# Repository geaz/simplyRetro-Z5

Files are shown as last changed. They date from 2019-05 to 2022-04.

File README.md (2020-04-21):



This repository contains everything to rebuild the *simplyRetro Z5*.
The *Z5* is my first attempt to build a custom emulation handheld from scratch.
It runs a custom linux image for emulation to accomplish a fast boot time (10 seconds).
But you are also able to use Retropie or Lakka for example (in both case you will loose the on screen battery indicator).

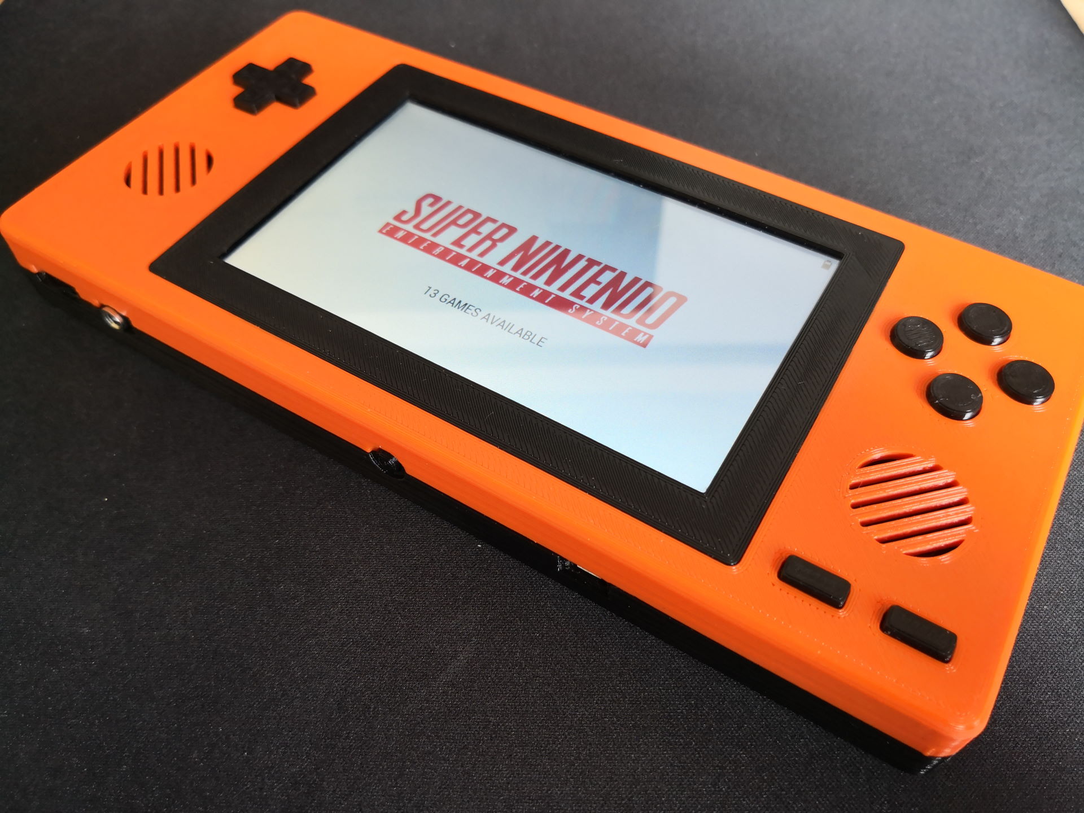
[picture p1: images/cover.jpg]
simplyRetro Z5


You can find a small video of it in action on [Youtube](https://www.youtube.com/watch?v=HvgBQ3S0Ykw).

## Warning
This is my first self designed retro handheld. So please be aware that it could contain some flaws. Furthermore you should be able to handle a soldering iron and you have to understand basic circuits, if you want to rebuild the Z5. Please make sure that you understand the steps in the build section, before you decide to rebuild the handheld.

## Features
- Custom 3D printed shell
- Custom linux distribution for fast boot ([from button press to emulationstation in 10 seconds](https://imgur.com/a/TFRGUFs))
- Single press power on and long press power off
- Battery Monitor icon and safe shutdown
- Stereo Speakers, Audio Jack and Volume Control
- 12 Buttons
- 5 inch display
- Raspberry Pi Zero powered

The Pi Zero and the 5 inch display are the reason for the naming *Z5*.

## 3D Model
The model was designed in Fusion360. If you want to change the design, you can find the whole model [here](https://a360.co/2GZACGc). The STLs are in the Thingiverse downloads and the Github repository. Furthermore there are exported STEP and Fusion360 Archive Files ready to download.

## BOM

- 3D Printed Shell (STL folder for models)
- [Elecrow 5 inch Display](https://www.elecrow.com/5-inch-hdmi-800-x-480-capacitive-touch-lcd-display-for-raspberry-pi-pc-sony-ps4.html) (If you want to use another display, make sure to adapt the shell) 
- [12x Adafruit Softbuttons](https://www.adafruit.com/product/3101)
- 1x 5mm Tactile Button for the Power Button
- [1x Powerboost 1000c](https://www.adafruit.com/product/2465)
- [2x Speaker](https://www.reichelt.de/kleinlautsprecher-k-34-wp-1w-8ohm-vis-2981-p204642.html?&trstct=pos_0) (or similar, just make sure they are 1W, 8Ohm and have a diameter of 3.4 cm)
- [FPV HDMI Adapter](https://de.aliexpress.com/item/FPV-Micro-HDMI-Mini-HDMI-90-grad-Adapter-5-cm-100-cm-FPC-Band-Flache-Hdmi/32833580742.html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) (1xA1, 1xC1 and 1x5cm Cable)
- 1x MCP3008 ADC
- 1x Volume potentiometer (I took a GameBoy Color replacement part)
- [1x Jack Plug PJ-307](https://de.aliexpress.com/item/Hot-10-Pcs-5-Pin-3-5mm-Weibliche-Audio-Stereo-Jack-Buchse-PJ-307-PJ307-3F07/32955627960.html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)
- 1x PAM8403 (Audio AMP)
- 1x 2500 mAh LiPo ([like this one](https://www.ebay.de/itm/LiPo-Akku-Lithium-Ion-Polymer-Batterie-3-7V-2500mAh-JST-PH-Connector-ZB07008/283213408497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))
- [Stripboard](https://www.amazon.com/ST3U-StripBoard-3U-Uncut-Strips-Sided/dp/B00C9NXP94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) (if you want to use the same circuits as me for the battery monitoring and safe shutdown)
- Some M3x8mm screws (Mounts and Shell), M2.5x4mm screws (Electronics) and one M2.5x8mm screw (Top screw on the bottom shell, has to be smaller to get it fit)
- Resistors (6,8K, 10K, 100K)
- 1N4001 Diodes
- Velcro or double-faced adhesive tape to attach the PAM and circuits
- Wire :)

### Alternative BOMs

Thanks to [AxelNobody](https://www.thingiverse.com/AxelNobody/about)! He created a [alternative BOM](https://github.com/geaz/simplyRetro-Z5/blob/master/BOM%20-%20US.md) with shop links for US citizens.

## Build
This chapter should help you to build the Z5. If you are missing something, or think it could be phrased better, you are free to create a *Pull Request* on Github. This way, together we can create a guide which is easy to understand! I will always keep the description on Thingiverse in sync to the *Readme* on Github.

**Again, please be aware, that you should have basic soldering skills and you should be able to understand basic circuits. Make sure that you understand the steps in the build section, before you decide to rebuild the handheld.**

I hope you got all your parts. Now it is time to assemble the Z5. 

### Buttons
This part is easy. Take all your printed button mounts and insert the *Adafruit SoftButtons* into them. It should be a tight fit. Use a pliers, if necessary and bend one of the four button pins to prevent it to fell out from the mount. Insert the printed DPad and buttons into the upper shell and screw the populated button mounts on top. **On the DPad please don't insert the upper right screw, and on the button mount the upper left screw, yet. These holes will be used to fasten the bottom half of the shell.** The *Shoulder Buttons* and *Shoulder Button Mounts* will be inserted into the shell before it gets closed. 

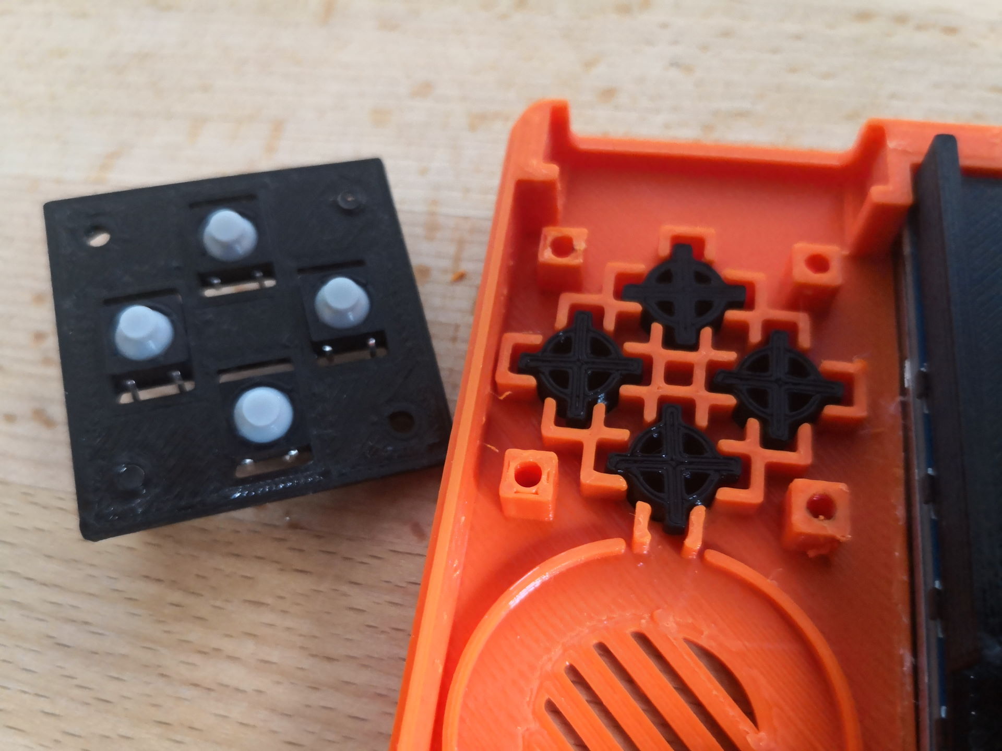
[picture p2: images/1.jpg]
simplyRetro Z5 - Buttons


### Display
**You have to install the display rotated by 180°**. Otherwise we will get space problems with the HDMI connectors. 

To fit the display into the shell, you have to cut off half of the bottom display mounts. 
Please use the following two pictures as a reference.  
**Make sure you understand how to place the display, in the correct orientation, into the shell BEFORE you cut the mounts!**

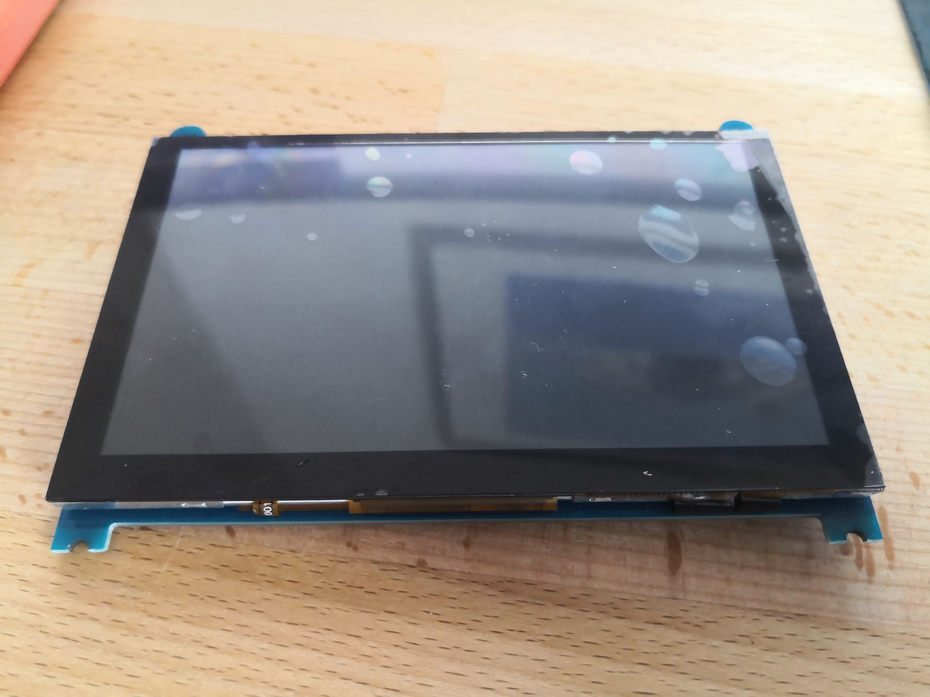
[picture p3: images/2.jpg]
simplyRetro Z5 - Display cutted


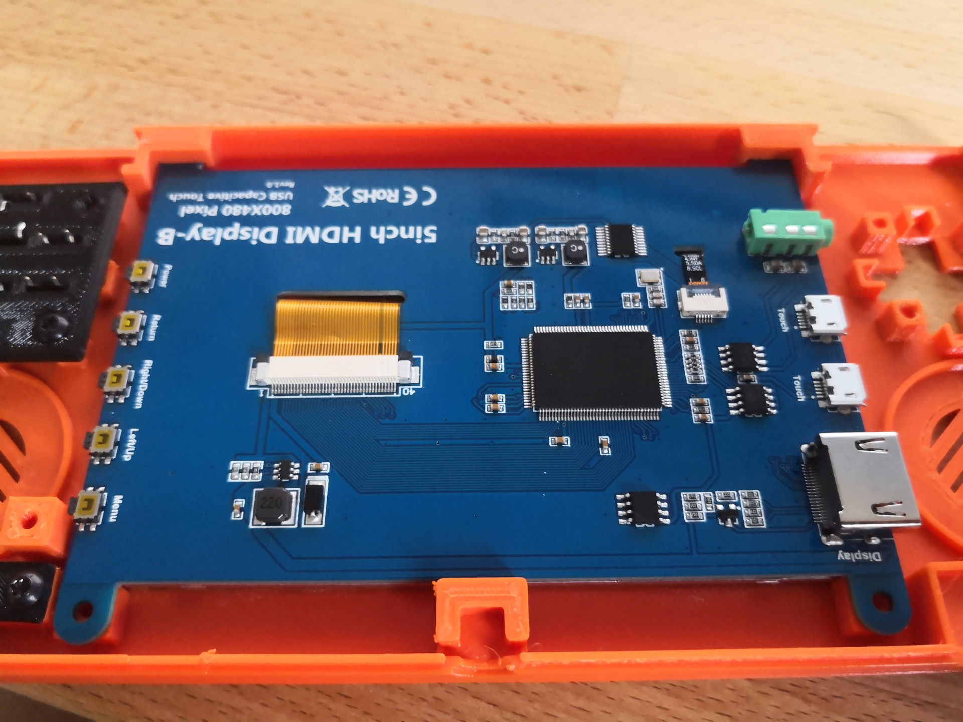
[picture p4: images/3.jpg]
simplyRetro Z5 - Display assembled


If your display is fitting into the top shell, you can remove it to glue the *Display Frame* to the upper shell. I used super glue. **Give it enough time to dry before you proceed. Otherwise you will ruin your display!**

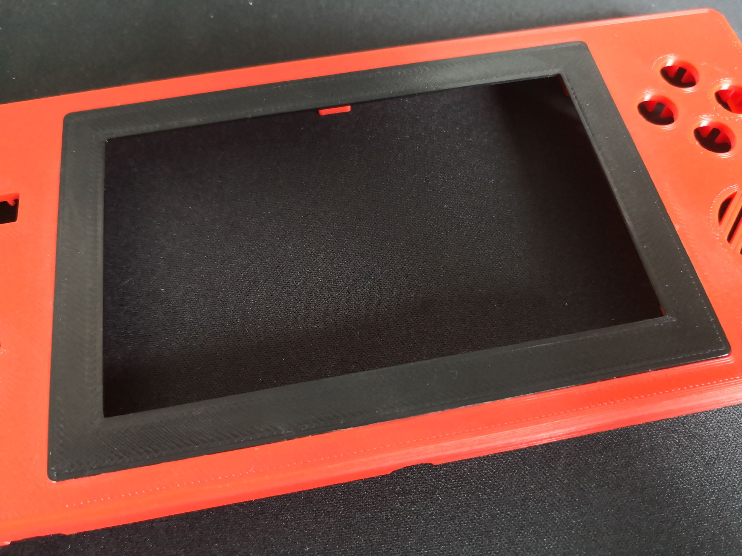
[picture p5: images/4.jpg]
simplyRetro Z5 - Display Frame


### Electronic Mount
Now take the *Electronic Mount* and use for example a bit felt at the edge without mount holes (see the following picture). The felt just acts as a spacer between the display PCB and the *Electronic Mount*.

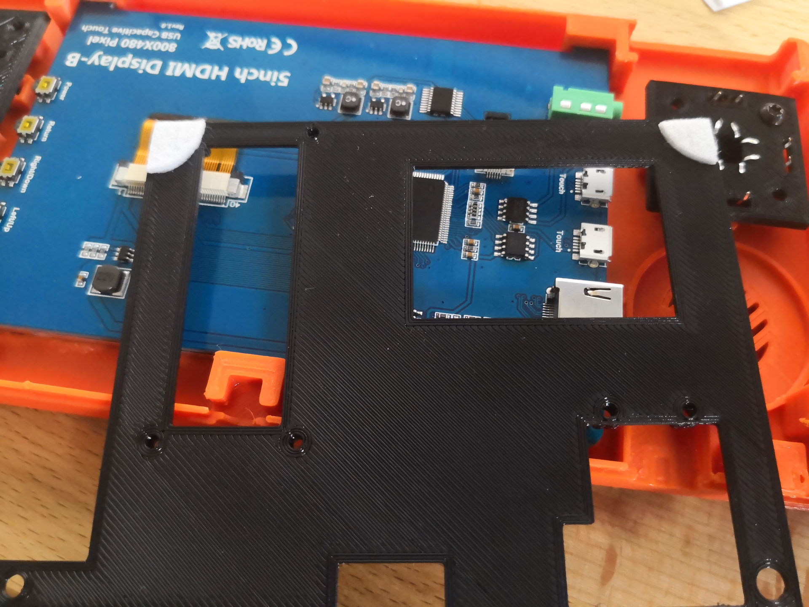
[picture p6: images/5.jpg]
simplyRetro Z5 - Electronic Mount Felt


Now take the printed spacers and two M3x8mm screws and attach the mount to the display.

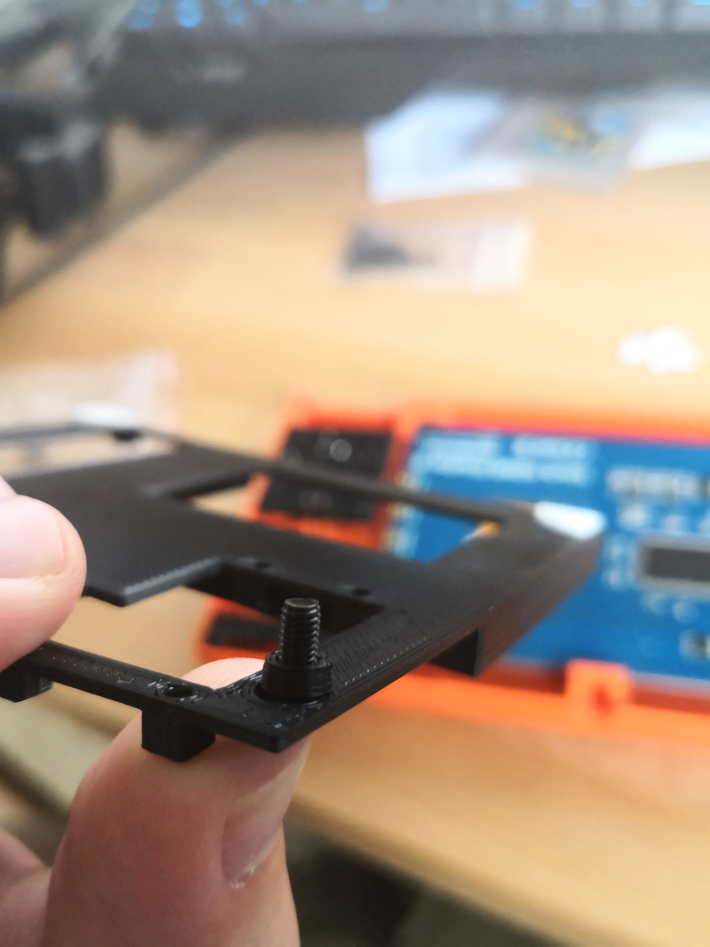
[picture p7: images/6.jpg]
simplyRetro Z5 - Electronic Mount Spacers


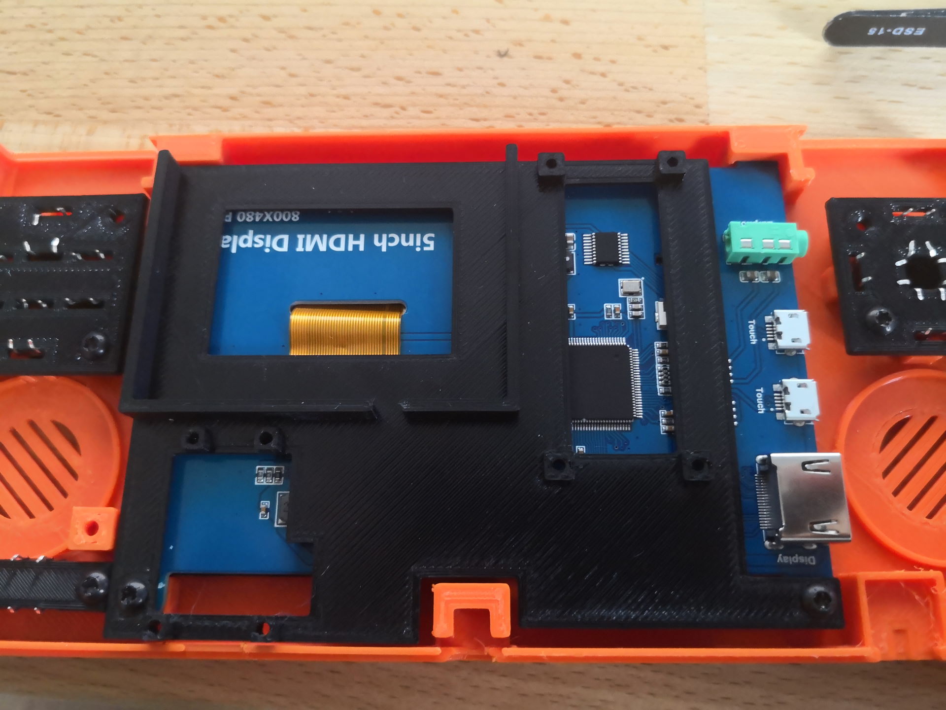
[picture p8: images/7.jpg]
simplyRetro Z5 - Electronic Mount assembled


### Power
To power the Raspberry Pi Zero through the Powerboost 1000C, I soldered the PowerBoost to the USB test pads of the Raspberry Pi. 
I used the same pads to solder a short Micro USB cable (I used the one which came with the display) to power the display. Unfortunately I don't have a picture of this.
Just search for the pinout of a micro USB adapter. You just need the *Vcc* and *GND*. If you are not sure which cable is which on your adapter, try to measure it with a multimeter.

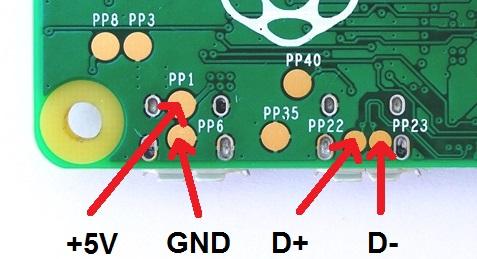
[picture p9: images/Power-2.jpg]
simplyRetro Z5 - Test Pads

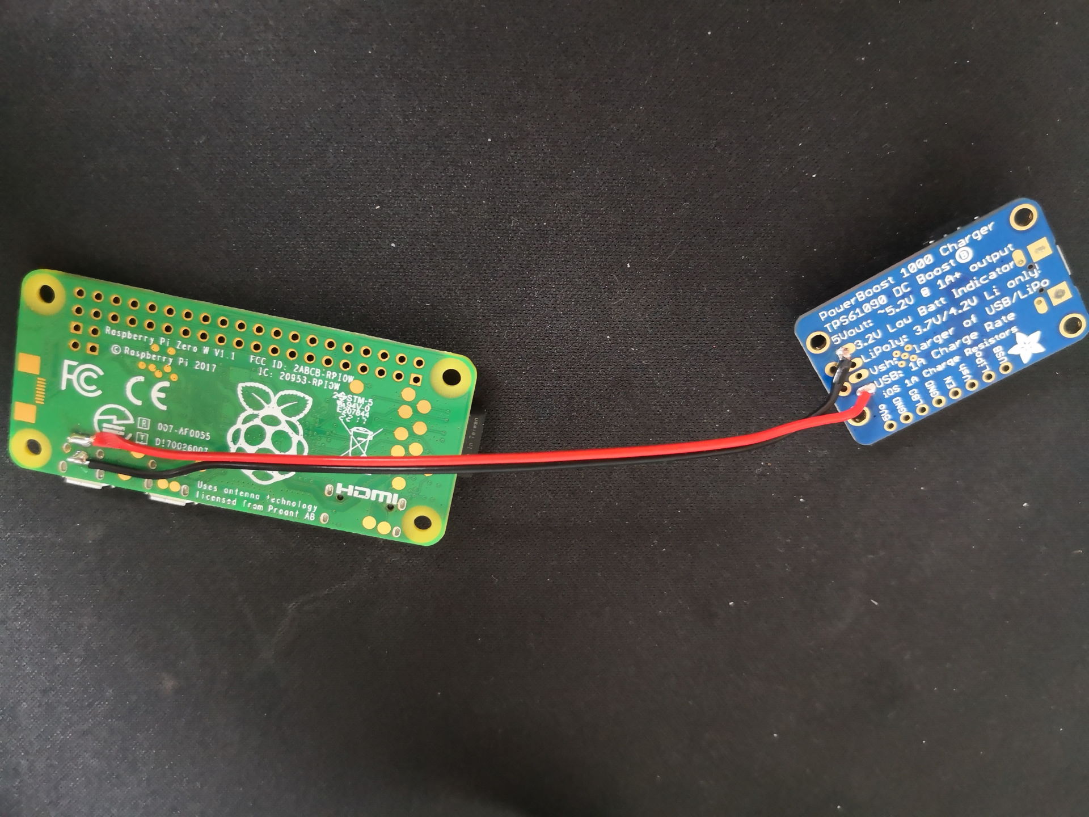
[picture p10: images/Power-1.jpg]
simplyRetro Z5 - PowerBoost Soldered


Now you need to do your first little circuit for this project. The circuit to power the Pi on and off.
You will need a piece of the Stripboard, the single tactile switch, three diodes, 1x100k and 2x10k resistors. 
Before you start soldering, you should do the needed cuts on the Stripboard. 

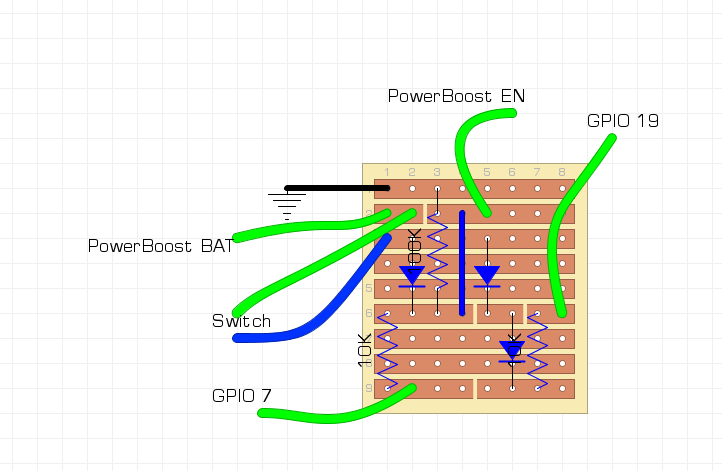
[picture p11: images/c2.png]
simplyRetro Z5 - Power Circuit


The circuit needs a bit of explanation. If the switch is not pressed, the *Enable* pin of the *PowerBoost* gets pulled to ground. This way the *PowerBoost* will be disabled when a battery is connected. As soon as the switch gets pressed, the *Battery* pin of the *PowerBoost* gets connected to the *Enabled* pin. This will enable the *PowerBoost*. Because we connected GPIO 7 of the Pi to the board the *Enable* pin will stay *HIGH* when the switch gets released and the board will stay powered on. You are able to use another pin than GPIO 7, but you have to make sure that you use a pin which is *HIGH* per default. 

GPIO 19 is used as the power off pin. The *simplyRetro Z5* custom distribution contains a small tool which listens to GPIO 19. If this pin gets *HIGH* and stays *HIGH* for a small amount of time a shutdown of the Pi gets initiated. 

Because of the line

*dtoverlay=gpio-poweroff,gpiopin=7,active_low=1*

in the config.txt, GPIO 7 will go *LOW*, if the Pi is shutdown. This disables the *PowerBoost* again.

Attach the switch into the bottom of the top shell half. I took a little drop of super glue to fix it in place.

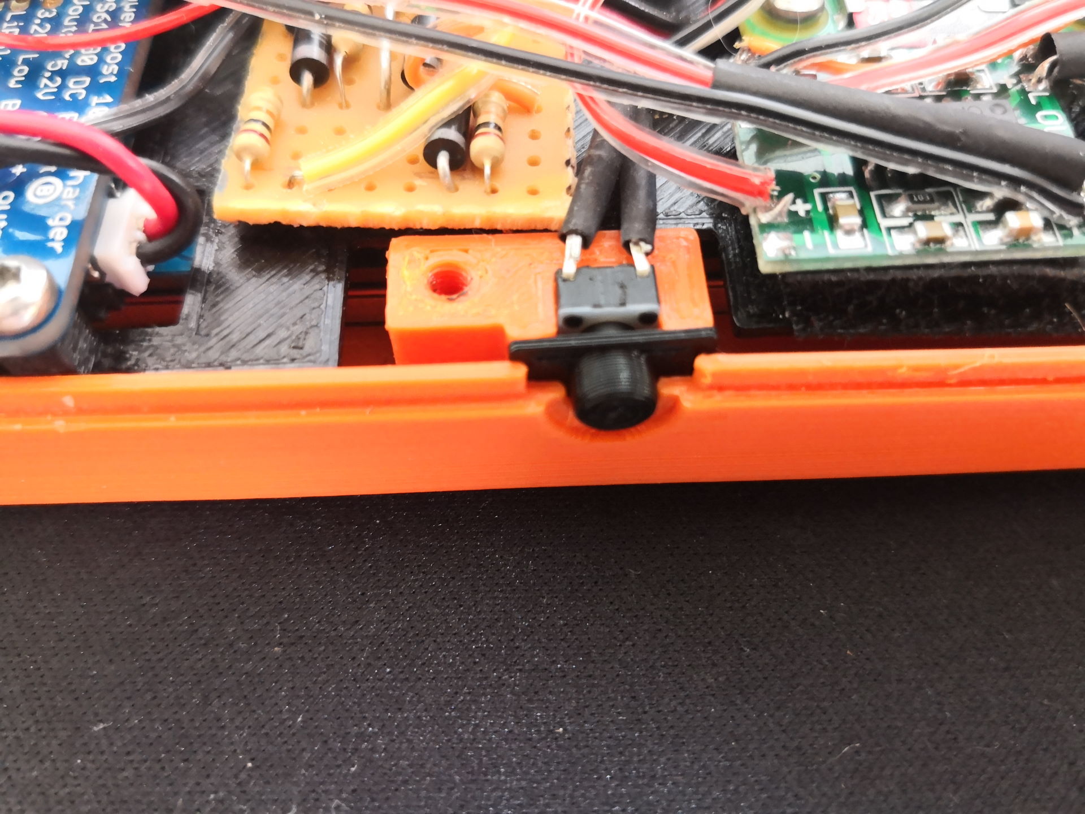
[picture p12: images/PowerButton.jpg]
simplyRetro Z5 - Power Button


Because the battery monitor and the controller also need several ground wires, I cutted an additional piece of Stripboard of 1x5 in size and used this as a single ground to the Pi.

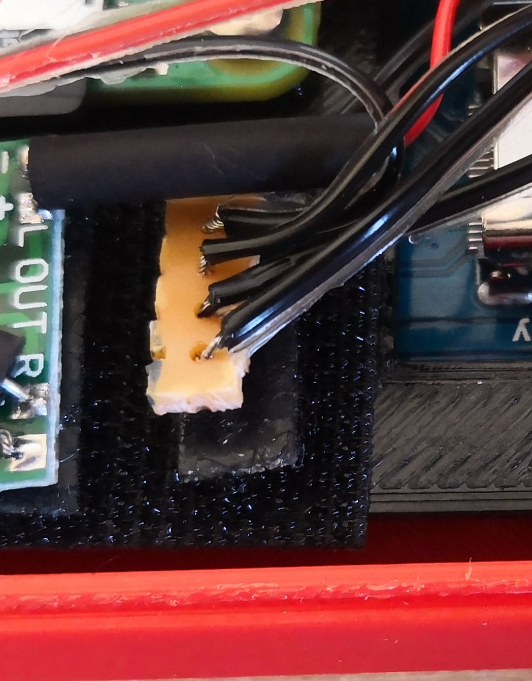
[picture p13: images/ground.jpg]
simplyRetro Z5 - Ground


### Controls
The *simplyRetro Z5* uses *Adafruits Retrogame* for its controller inputs. 

To make the softbuttons work, each button has to be connected to ground and one pin on the Raspberry Pi.
I connected the ground pins on the DPad together and used just one ground pin on the Raspberry Pi for all four buttons.
I did the same for the four buttons on the right and the *Start*, *Select* button. You could also use a piece of Stripboard to just use one
ground pin of the Raspberry Pi and connect all ground wires of the buttons just to this Stripboard.

If you want to use the exact same configuration for *Retrogame* you can use the following pins.

```
LEFT      16  # Joypad left
RIGHT     17  # Joypad right
DOWN      4   # Joypad down
UP        2   # Joypad up
Z         23  # 'B' button 
X         24  # 'A' button 
A         0   # 'Y' button 
S         25  # 'X' button 
Q         26  # Left shoulder button
W         5   # Right shoulder button
SPACE	  22  # 'Select' button
ENTER     27  # 'Start' button
```

### Audio
The *simyplRetro Z5* takes the audio source directly from the HDMI display. Use a piece of the Stripboard (1x4 in size) as the ground connection.
**Don't connect the ground of the PAM! Otherwise you will create a ground loop which will cause interferences in you audio circuit!**

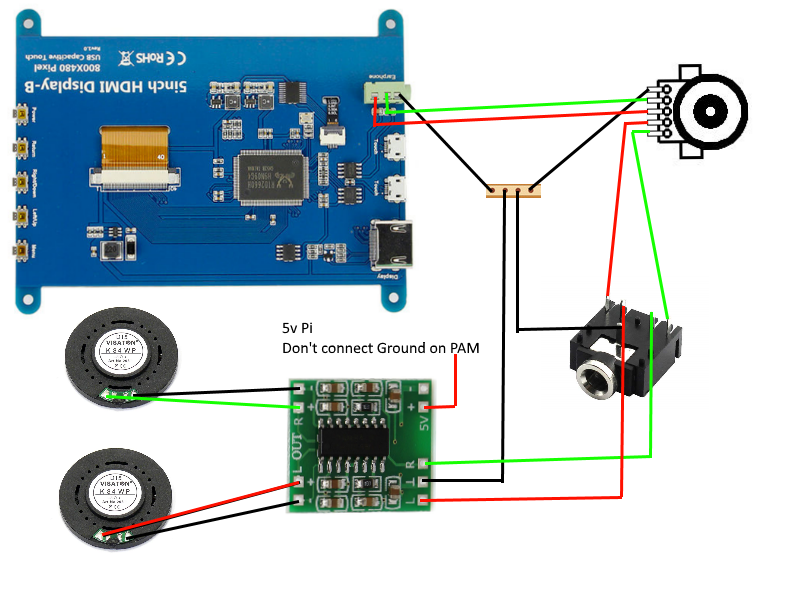
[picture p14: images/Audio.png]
simplyRetro Z5 - Audio


I attached the potentiometer with a little drop of hot glue. The audio jack plug should be press fit.

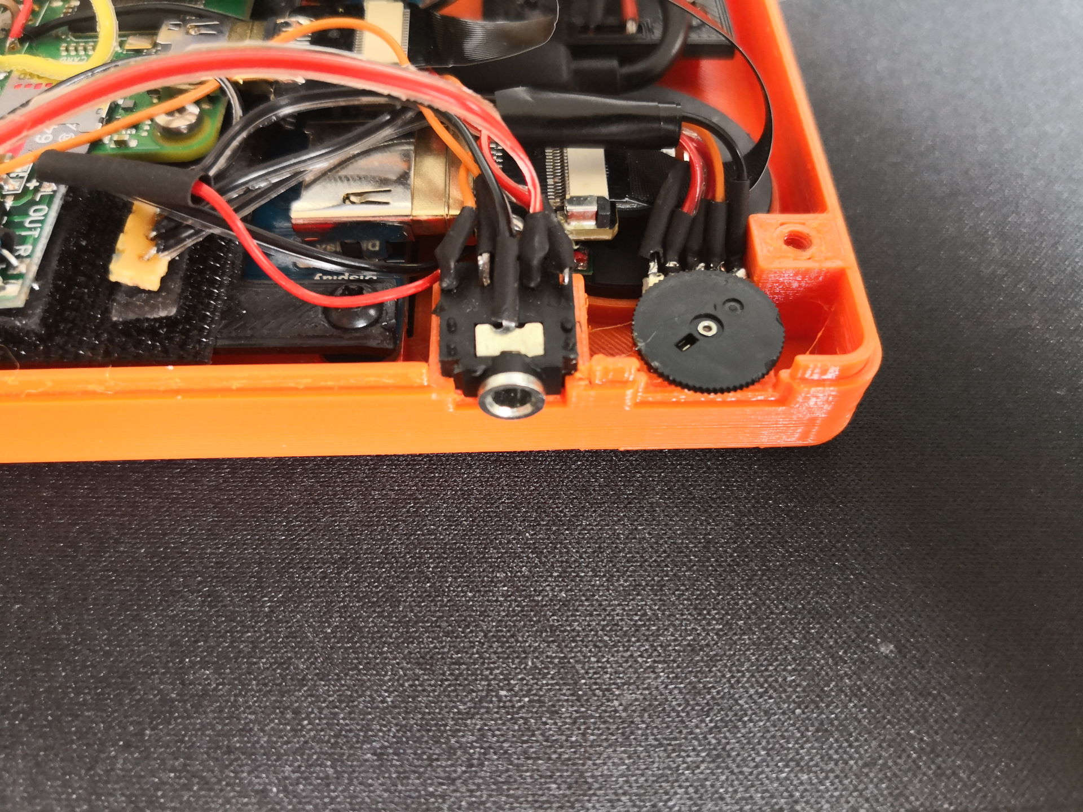
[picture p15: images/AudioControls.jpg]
simplyRetro Z5 - Audio


### Battery Monitor
For this step you will again need a bit of the Stripboard, the MCP3008, two 6.8k and two 10k resistors.
Again make sure to do the cuts on the Stripboard, before you start soldering. Solder everyhing as referenced in the following picture.
You should use the exact same pins, if you want the battery monitor tool in the custom distribution to work.

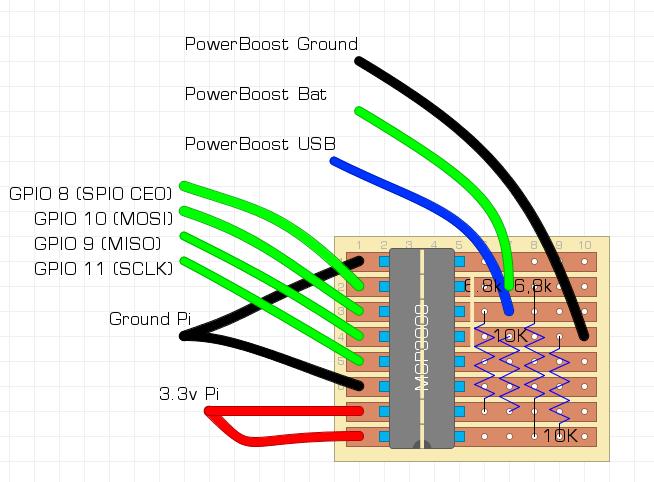
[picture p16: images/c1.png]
simplyRetro Z5 - ADC Circuit


I attached the board with Velcro on top of the right speaker.

### Closing the shell
Finally your internals may look something likes this (or not so messy...).

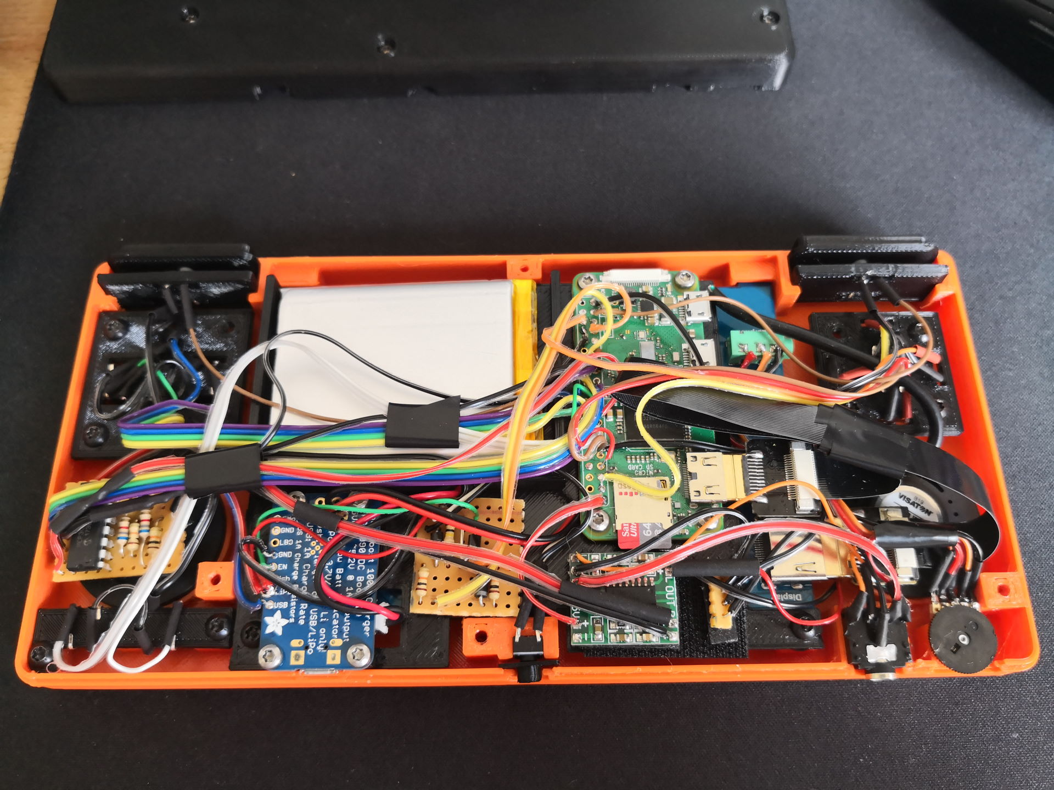
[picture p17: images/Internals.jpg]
simplyRetro Z5 - Internals


As soon as your SD card is flashed and everything is working, you are able to close the shell. Use five M3x8mm and one M2.5x8mm. Be careful, that the screw holes are free from wires. You don't want to damage them when you screw the shell halves together. After this last step is done, go and enjoy your *simplyRetro Z5*! Have fun :)

## Custom Distribution
The custom distribution can be downloaded [here](https://github.com/geaz/simplyRetro-Z5/releases).  
It is based on [BuildRoot](https://buildroot.org/) and just contains the packages needed to play on the *Z5*. 

**Please be aware, that the distribution was build for the Z5! It was not tested as a standalone distribution.**

The *Z5* uses Retroarch for all emulations. The following systems are supported at the moment (more can be added):

- Arcade (MAME2013-plus - BIOS needed)
- Gameboy DMG / Color (Gambatte)
- Gameboy Advance (gpsp - BIOS needed)
- NES (quicknes)
- SNES (snes9x2002)
- Meda Drive / Master System / Sega CD (picodrive - BIOS needed for Sega CD)

If you want to use the distribution just use Etcher to copy the img file to a SD Card.

### Boot Partition

#### config.txt
Please be aware, that the default config.txt will rotate the screen. This is necessary, if you are you using the same screen as me.

#### retrogame.cfg
The Z5 uses RetroGame by Adafruit for the controller. In this file you are able to set the pins you used during the build.

#### retropower.cfg
If you used another GPIO than pin 19 for the power off button, you are able to set it in this file. Please be aware, that you have to use the WiringPi number of the GPIO pin.
Use for example [https://de.pinout.xyz/](https://de.pinout.xyz/) to check the pin numbering. If you don't want to use the battery monitoring and/or power circuit, you are able to change the active features in this file.

### Login
Start the system and login with:

User: root  
Pass: simplyretro

### Resize Root
To use the full size of you SD Card you should execute the following two scripts in order:

/root/reformat.sh (will reboot the system after execution)  
/root/resize.sh

### WiFi, FTP & SSH
You are able to set your WiFi SSID and PSK through the Emulationstation menu. Press 'Start' and go into the 'simplyRetro' menu.
After setting the WiFi, just enable any service you need. **I recommend to disable the services after usage to reduce battery load and 
to speed up the boot process.**

### ROMs and BIOS folder
The ROMs and BIOS folder are located at */root/roms* and */root/bios*. You are able to change the splash screen, if you want. It is also located at the */root* folder.

### Controls
EmulationStation will ask you to configure your controller on the first start.  
Retro Arch is configured to exit a ROM, if you press *START + B*.  
You are able to open the Retro Arch menu while playing a game, if you press *START + A*.

### Updates
If there will be an update to the distribution, I will try to distribute the updated files together with the image. This way you are able to update just these files via FTP and don't have to flash the whole image again.

## Credits
Thanks to [NeoHorizon](https://github.com/NeonHorizon/lipopi) and [Craic](https://github.com/craic/pi_power) for the work on the power circuits. I took their work and reworked the circuit a bit and created a custom battery monitor in C.  
Thanks to [BuildRoot](https://buildroot.org/) for the creation of this great system which enabled me to create a custom linux distribution.  
Thanks to [RecalBox](https://www.recalbox.com/) for their work on the packages for BuildRoot. I took the RetroArch and LibRetro packages and reworked them a bit to work on my distribution. Also thanks for the code of the on screen keyboard!
Thanks to [ehettervik](https://retropie.org.uk/forum/topic/4611/runcommand-system-splashscreens) for the emulator splashscreens.
Thanks to [ProGM](https://progm.itch.io/doctor-how) for the GB homebrew game.

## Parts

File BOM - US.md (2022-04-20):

BOM for the US by [AxelNobody](https://www.thingiverse.com/AxelNobody/about)

| Part | Source | Notes |
|---|---|---|
| Elecrow 5 inch Display | [Amazon](https://www.amazon.com/Elecrow-Capacitive-interface-Supports-Raspberry/dp/B07FDYXPT7) |  |
| 12x Adafruit Softbuttons | [Amazon](https://www.amazon.com/gp/product/B07KKN7GPB) [Mouser](https://www.mouser.com/ProductDetail/485-3101) |  |
| 1x 5mm Tactile Button for the Power Button | [Adafruit](https://www.adafruit.com/product/367) [Mouser](https://www.mouser.com/ProductDetail/485-367) |  |
| 1x Powerboost 1000c | [Amazon](https://www.amazon.com/gp/product/B01BMRBTH2) [Mouser](https://www.mouser.com/ProductDetail/485-2465) |  |
| 2x Speaker | [Amazon](https://www.amazon.com/gp/product/B00O9YHIDA/) [Mouser](https://www.mouser.com/ProductDetail/243-K34WP-8OHM) | The Amazon speakers are suitable alternatives.  They can be attached with hot glue.  The Mouser sourced speakers are identical to the original |
| FPV HDMI Adapter (1xA1, 1xC1 and 1x5cm Cable) | [See Issue](https://github.com/geaz/simplyRetro-Z5/issues/16) |  |
| 1x MCP3008 ADC | [Adafruit](https://www.adafruit.com/product/856) [Mouser](https://www.mouser.com/ProductDetail/579-MCP3008-I-P) |  |
| 1x Volume potentiometer | [Amazon](https://www.amazon.com/gp/product/B00O9Y6Z70) [Mouser(Untested)](https://www.mouser.com/ProductDetail/688-RK10J12E0A0A) |  |
| 1x Jack Plug PJ-307 | [Adafruit](https://www.adafruit.com/product/1699) [Mouser](https://www.mouser.com/ProductDetail/485-1699) |  |
| 1x PAM8403 (Audio AMP) | [Amazon](https://www.amazon.com/gp/product/B00LODGV64/) |  |
| 1x 2500 mAh LiPo | [Adafruit](https://www.adafruit.com/product/328) |  |
| Stripboard | [Amazon](https://www.amazon.com/gp/product/B00C9NXP94) |  |
| M3x8mm screws (Mounts and Shell) | [Amazon](https://www.amazon.com/gp/product/B016YZTEDI) |  |
| M2.5x4mm screws (Electronics) | [Amazon](https://www.amazon.com/gp/product/B07HC3LQYS) |  |
| Resistor Pack (needs 6.8k, 10k, 100k) | [Amazon](https://www.amazon.com/gp/product/B016NXK6QK/) |  |
| OR |
| 6.8k Resistors | [Mouser](https://www.mouser.com/ProductDetail/660-MF1-4LCT52R682G) |  |
| 10k Resistors | [Mouser](https://www.mouser.com/ProductDetail/660-MF1-4LCT52R103G) |  |
| 100k Resistors | [Mouser](https://www.mouser.com/ProductDetail/660-MF1-4LCT52R104G) |  |
| 1N4001 Diodes | [Adafruit](https://www.adafruit.com/product/755) [Mouser](https://www.mouser.com/ProductDetail/863-1N4001G) |  |
| Velcro or double-faced adhesive tape to attach the PAM and circuits | [Amazon](https://www.amazon.com/gp/product/B00006IF60/) |  |
| Raspberry Pi Zero W | [Adafruit](https://www.adafruit.com/product/3400) [Mouser](https://www.mouser.com/ProductDetail/713-110991027) |  |
| Wire | Use what you have :) |  |

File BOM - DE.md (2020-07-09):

BOM for Germany by [Phil](https://www.thingiverse.com/leseule/)

| Part | Source | Price |
|---|---|---|
| Elecrow 5 inch Display | [Aliexpress](https://de.aliexpress.com/item/32889893278.html) | 40,49 € |
| 12x Adafruit Softbuttons | [Aliexpress](https://de.aliexpress.com/item/32668706990.html) | 2,31 € |
| 1x 5mm Tactile Button for the Power Button | [Aliexpress](https://de.aliexpress.com/item/32668706990.html) | use as the US-list a 6mm button |
| 1x Powerboost 1000c | [Digikey](https://www.digikey.de/product-detail/en/adafruit-industries-llc/2465/1528-1349-ND/5356834) | 18,12 € |
| 2x Speaker | [Aliexpress](https://de.aliexpress.com/item/33037641624.html) | 0,90 € |
| FPV HDMI Adapter (1xA1, 1xC1 and 1x5cm Cable) | [Aliexpress](https://de.aliexpress.com/item/32833580742.html) | 10,28 € |
| 1x MCP3008 ADC | [Digikey](https://www.digikey.de/product-detail/en/microchip-technology/MCP3008-I-P/MCP3008-I-P-ND/319422) | 1,94 € |
| 1x Volume potentiometer | [Aliexpress](https://de.aliexpress.com/item/32968867573.html) | 0,63 € |
| 1x Jack Plug PJ-307 | [Aliexpress](https://de.aliexpress.com/item/32955627960.html) | 0,09 € |
| 1x PAM8403 (Audio AMP) | [eBay](https://www.ebay.de/itm/5PCS-2-Channel-3W-Digital-Power-PAM8403-Class-D-Audio-Amplifier-Board-USB-DC-5V/264406885127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) | 0,46 € |
| 1x 2500 mAh LiPo | [Eckstein](https://eckstein-shop.de/LiPo-Akku-Lithium-Ion-Polymer-Batterie-37V-2500mAh-JST-PH-Connector) | 8,94 € |
| Stripboard | [Aliexpress](https://de.aliexpress.com/item/32847898011.html) | 0,92 € |
| M3x8mm screws (Mounts and Shell) | [Digikey](https://www.digikey.de/products/de/hardware-fasteners-accessories/screws-bolts/572?k=M3x8) | 0,56 € |
| M2.5x4mm screws (Electronics) | [Digikey](https://www.digikey.de/product-detail/de/essentra-components/50M025045P004/145-50M025045P004-ND/11638731) | 0,12 € |
| Resistor Pack (needs 6.8k, 10k, 100k) | [Eckstein](https://eckstein-shop.de/600x-Metallschicht-Metallfilm-Widerstaende-025W-20-bis1M-30-Sorten) | 3,53 € |
| 1N4001 Diodes | [Digikey](https://www.digikey.de/product-detail/de/comchip-technology/1N4001-G/641-1310-1-ND/1979675) | 0,09 € |
| Velcro or double-faced adhesive tape to attach the PAM and circuits | [Amazon](https://www.amazon.de/tesa-doppelseitiges-Montageband-Powerbond-Innen/dp/B0014E3L9I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) | 1 € |
| Wire Pack | [Eckstein](https://eckstein-shop.de/SparkFun-Hook-Up-Wire-Assortment-Stranded-22-AWG) | 1 € |
OR
| Wire | use what you have | |

Just ordered all parts till now (09.07.2020) due to the exactly same specs, so they should fit as planed.
Price in total at the actual day (without Raspberry Pi) around 100 €.
(Prices were calculated on the amount of usage. Also shipping costs where divided by the percentage of use.)

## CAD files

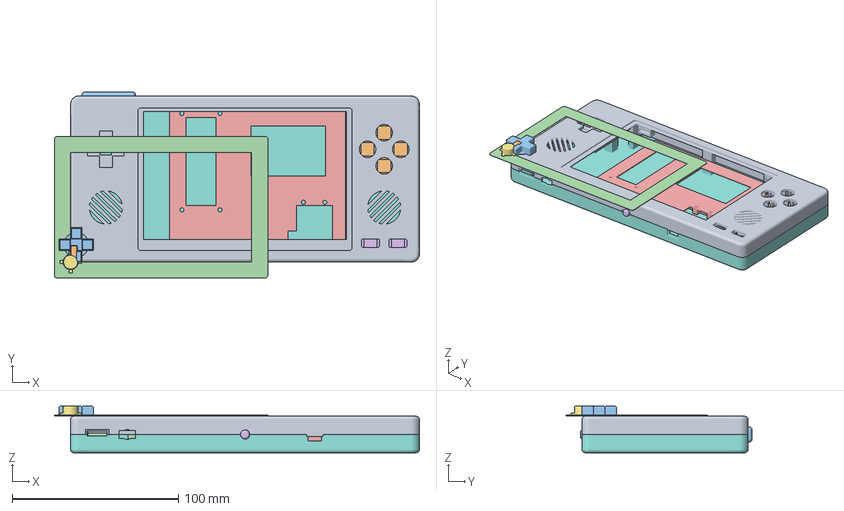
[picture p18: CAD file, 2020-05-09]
simplyRetro z5.3mf
219.7 x 112.2 x 28.0 mm
Top Shell.stl
2x Button.stl
2x Shoulder Button.stl
2x Shoulder Button Mount.stl
2x Spacer (5x3.5 - 2mm).stl
Control Mount C.stl
4x Button.stl
Bottom Shell.stl
Control Mount A.stl
Control Mount B.stl
Cross.stl
Display Frame.stl
Electronic Mount.stl
Power Button.stl

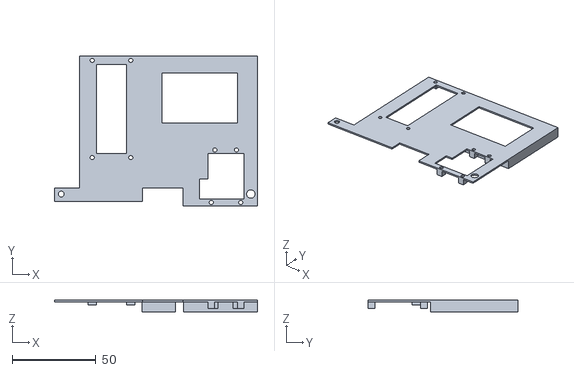
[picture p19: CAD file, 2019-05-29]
stl/Electronic Mount.stl
121.1 x 89.3 x 7.00

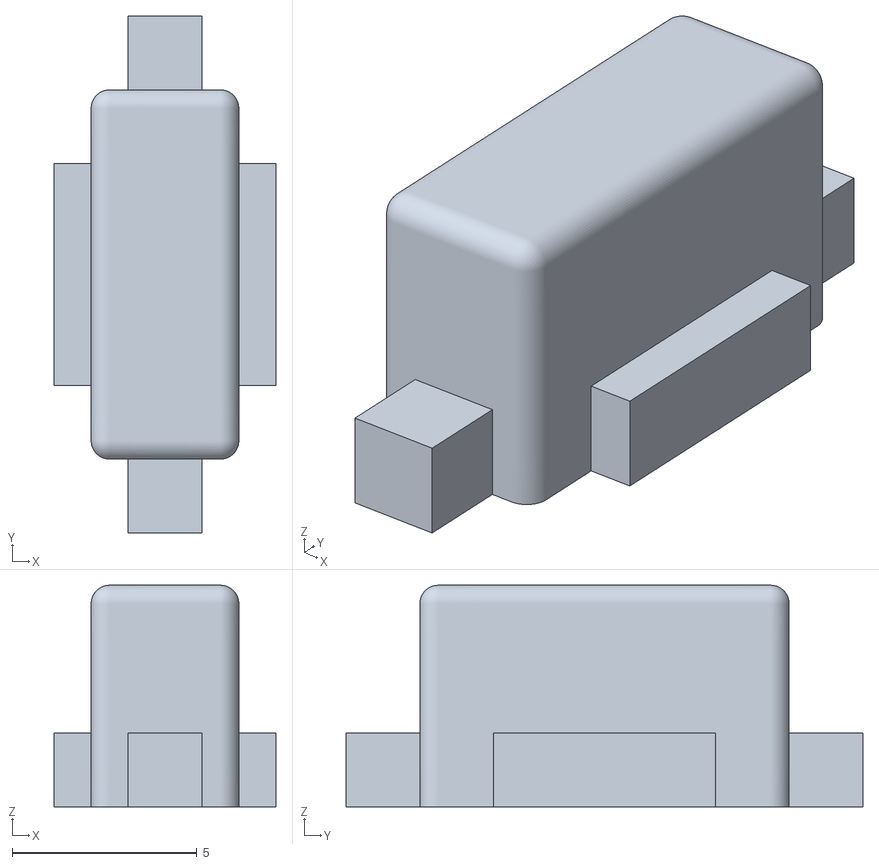
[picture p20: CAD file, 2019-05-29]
stl/2x Button.stl
6.00 x 14.0 x 6.00

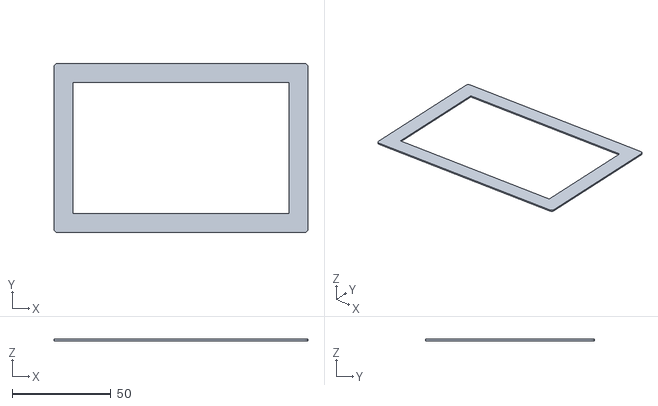
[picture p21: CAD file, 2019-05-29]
stl/Display Frame.stl
128.4 x 85.4 x 0.8

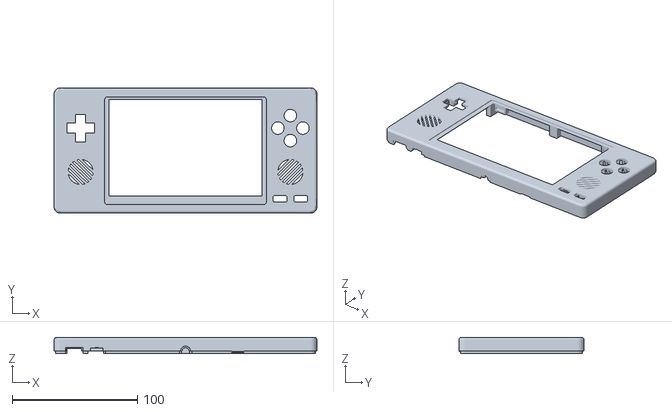
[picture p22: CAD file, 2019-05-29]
stl/Top Shell.stl
210.0 x 100.0 x 13.0

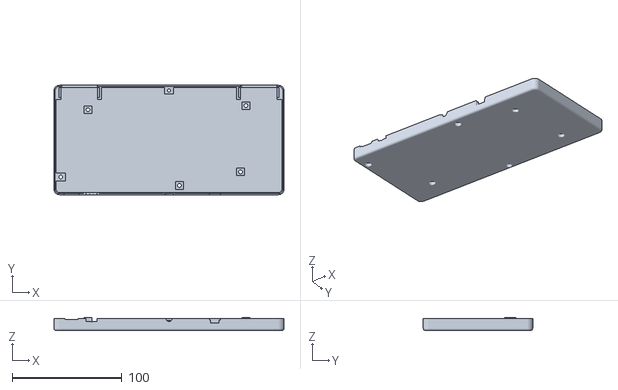
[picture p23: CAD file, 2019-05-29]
stl/Bottom Shell.stl
210.0 x 100.0 x 12.0

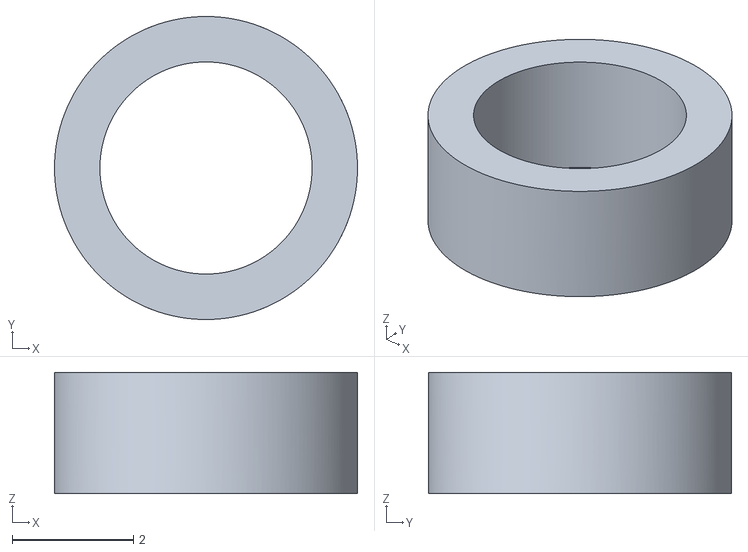
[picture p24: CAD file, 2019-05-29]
stl/2x Spacer (5x3.5 - 2mm).stl
5.00 x 5.00 x 2.00

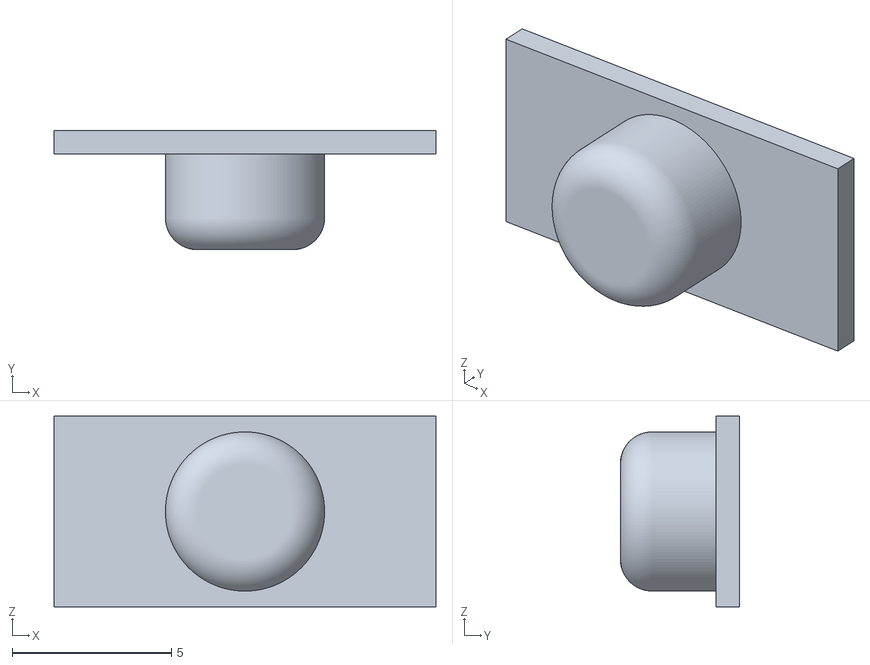
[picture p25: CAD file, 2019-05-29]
stl/Power Button.stl
12.0 x 3.75 x 6.00

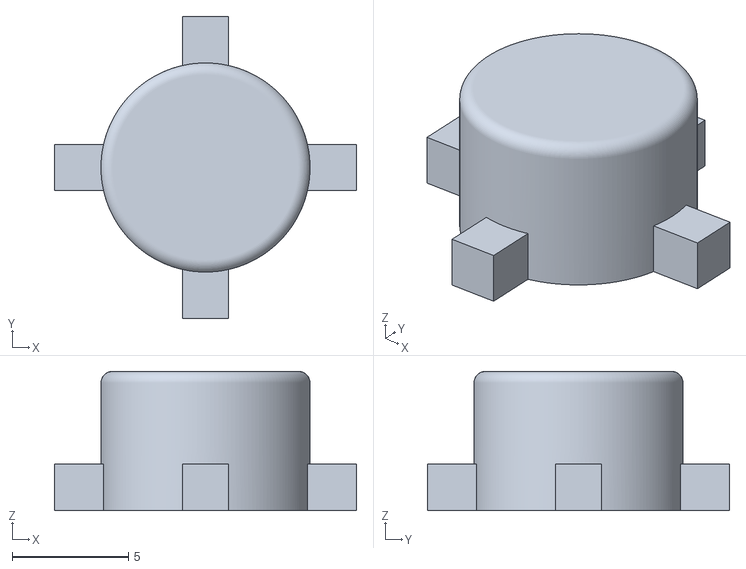
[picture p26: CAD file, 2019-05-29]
stl/4x Button.stl
13.0 x 13.0 x 6.00

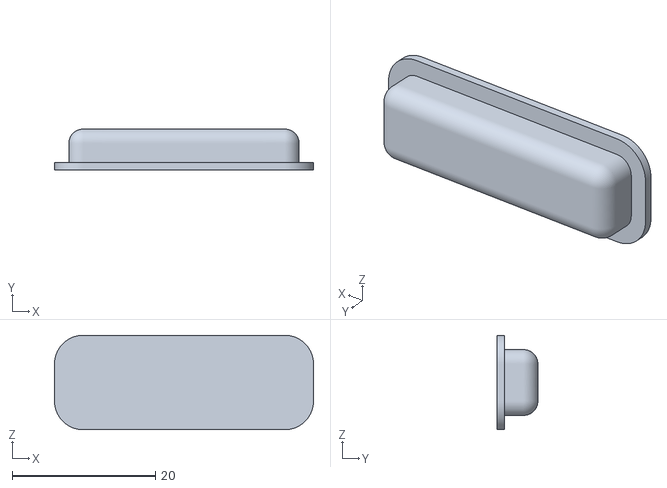
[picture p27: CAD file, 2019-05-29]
stl/2x Shoulder Button.stl
36.2 x 5.70 x 13.2

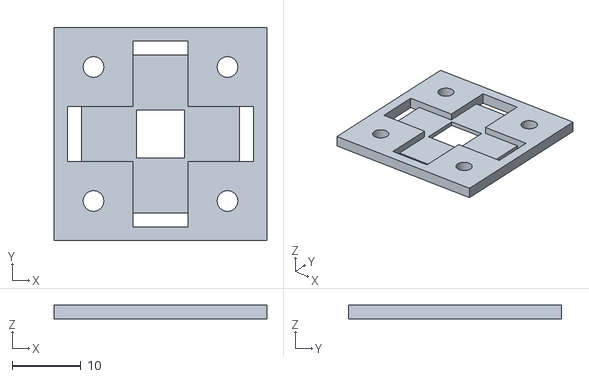
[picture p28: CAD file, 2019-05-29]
stl/Control Mount A.stl
31.0 x 31.0 x 2.00

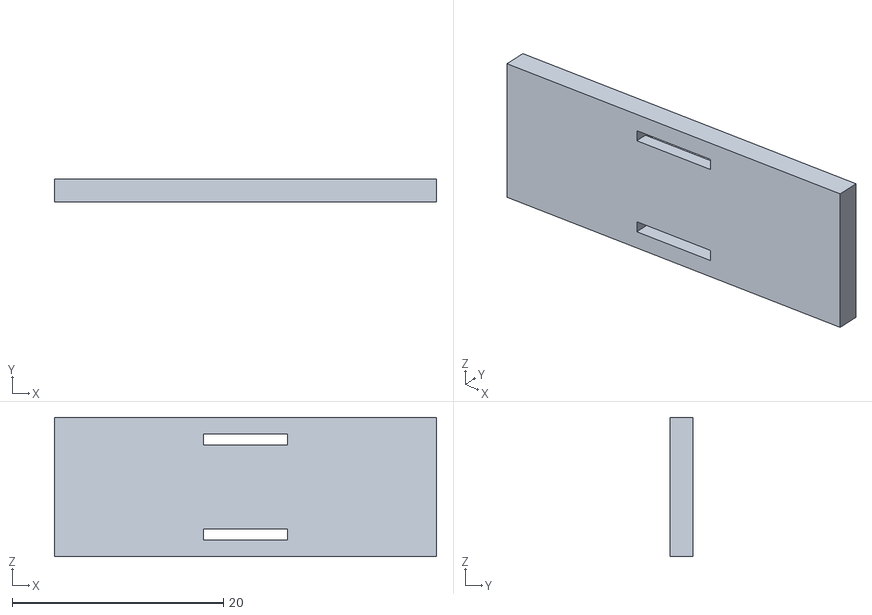
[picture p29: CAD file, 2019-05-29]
stl/2x Shoulder Button Mount.stl
36.2 x 2.20 x 13.2

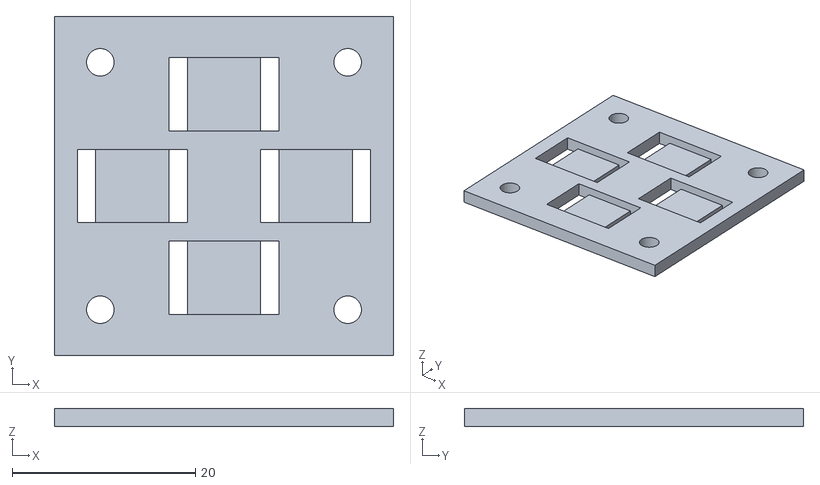
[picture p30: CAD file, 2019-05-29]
stl/Control Mount B.stl
37.0 x 37.0 x 2.00

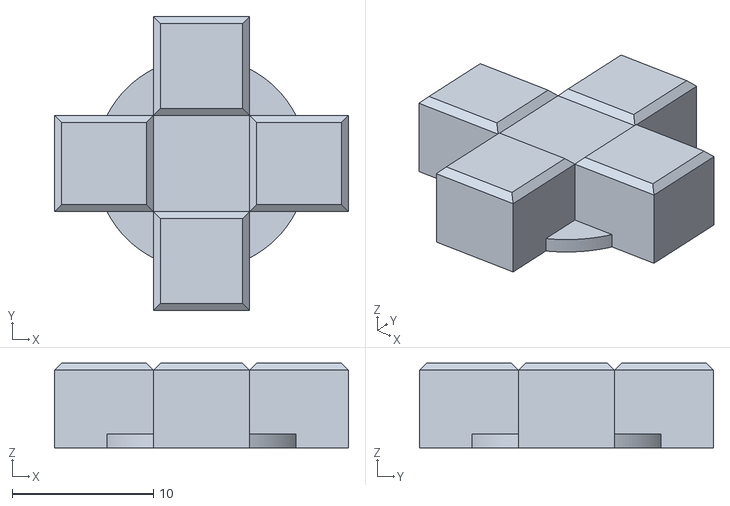
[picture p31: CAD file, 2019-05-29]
stl/Cross.stl
20.8 x 20.8 x 6.00

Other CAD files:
stl/Control Mount C.stl

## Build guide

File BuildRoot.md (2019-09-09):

The image was build with the LTS version - 2019.02.4 - of [BuildRoot](https://buildroot.org/downloads/buildroot-2019.02.4.tar.gz).

1. Download & Extract BuildRoot
2. Copy the content of the buildroot folder in the repository to the extracted buildroot LTS version
3. Add the content of the file buildroot/packages/Config.in.additions to the file packages/Config.in
4. sudo apt install libncurses5-dev
5. make simplyRetro-z5_defconfig
6. make menuconfig
7. make

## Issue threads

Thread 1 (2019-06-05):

Initial Loading Error

hoofta, 2019-06-05:
I used Etcher to load on the .img file and after showing the initial "SimplyRetro" logo I ended up getting this error (image attached)
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

geaz, 2019-06-05:
Which Pi are you using? Because the image is build for the Pi Zero W. Just asking to make this clear :)

hoofta, 2019-06-05:
Pi Zero W V1.1

geaz, 2019-06-05:
You could get the error because of several things. I built the image especially for the Z5. Therefore it could come to errors, if the power button is not present for example.

We could try two things:
1. Remove this line "dtoverlay=gpio-poweroff,gpiopin=7,active_low=1" from the config.txt
2. Because of a script, which gets started at the boot of the image, the GPIO 19 has to be pulled to LOW. Otherwise a shutdown will be initiated before it really booted...(this looks like the error you are getting)

geaz, 2019-06-05:
You could get the error because of several things. I built the image especially for the Z5. Therefore it could come to errors, if the power button is not present for example.

We could try two things:
1. Remove this line "dtoverlay=gpio-poweroff,gpiopin=7,active_low=1" from the config.txt
2. Because of a script, which gets started at the boot of the image, the GPIO 19 has to be pulled to LOW. Otherwise a shutdown will be initiated before it really booted...(this looks like the error you are getting)

hoofta, 2019-06-05:
Line removed commented out. Booted up, SimplyRetro logo came up and then pi shut down ("no signal appeared on screen"). I ordered the parts so I guess I might need to wait for them to arrive.

geaz, 2019-06-05:
Yep, seems like it is the shutdown script. Will try to add a config for this one in the following days (after I finished the "Build" chapter).

hoofta, 2019-06-05:
Very cool. I'll stay in contact when I get parts for build and keep you posted to help with more troubleshooting if I can. Thanks for your efforts on this. Definitely looks like a fun project. Can't wait!

geaz, 2019-06-05:
I will try my best to help you :)
Please be aware, that I added a Veroboard / Stripboard to the BOM. This is necessary for the safe shutdown and battery monitoring.

hoofta, 2019-06-05:
Do you have a link for the veroboard you used?

geaz, 2019-06-05:
Any Veroboard like this one will do it: https://www.amazon.com/ST3U-StripBoard-3U-Uncut-Strips-Sided/dp/B00C9NXP94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

It does not have to be that big. You will just need a 1x4, a 8x10 and a 8x9 piece.
Here are the pictures of the circuits for which it is needed:
https://github.com/geaz/simplyRetro-Z5/blob/master/images/c1.png
https://github.com/geaz/simplyRetro-Z5/blob/master/images/c2.png

geaz, 2019-06-06:
Added retropower.cfg to boot partition and changed power script to read this file on start. If you used another pin than GPIO 19 (WiringPi 24) just change it in this file. Or remove the file to disable the power script.

New image added to release V1.1

Closed 2019-06-06.

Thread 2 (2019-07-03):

Screen Mounting/Orientation Issue

hoofta, 2019-07-03:
I finally got all my components in, I printed the pieces and started your project! I followed your instructions about making sure I knew which was "up" was on the screen and what I received was opposite of yours. Unfortunately, this has now lead to the electronics mount being backward and the 5mm FPV HDMI Adapter to be too short. I don't know if there is a way for future builders to find this out before they purchase the screen. If the electronics board can be flipped where the pi zero is mounted on the left, and battery as well as the powerboard on the right, then I should be able to proceed just fine. I might be able to do some swapping/altering on the electronic board but I was figuring it might be quicker if you could flip it since you designed it.

This could all be fixed to if there was a rotate screen 180º command. This would then pose a problem for me since I've already cut my screw mounts on the screen, however, it would save a lot of hassle for future builds.

geaz, 2019-07-03:
Do you have a picture of you screen PCB? Would be really strange, if they produce it in different rotations.

The screen can be rotated in the config.txt. Per default I already rotated it by 180°, because I assembled my screen upside down. As you can see here: https://raw.githubusercontent.com/geaz/simplyRetro-Z5/master/images/3.jpg

hoofta, 2019-07-03:
Circles provided for perspective
![Uploading 2019-07-03 16.58.10.jpg…]()
![Uploading 2019-07-03 16.58.40.jpg…]()

geaz, 2019-07-03:
Ok, I see the problem. The screen seems to be ok. You just cutted the wrong mounts :)
Please look again at this picture: https://raw.githubusercontent.com/geaz/simplyRetro-Z5/master/images/3.jpg

The display gets mounted in the shell rotated by 180°.

I hoped my phrasing in the description "The display will be assembled upside down" and the picture would be enough to make it clear.

hoofta, 2019-07-03:
When I read "the display will be assembled upside down I saw that as it was upside down in the frame as it was being built. I now see what you are saying that it is mean to be installed upside to be rotated within the R.pi. Thanks for taking to explain it.

geaz, 2019-07-04:
Ah I see why my description was misleading. I tried to rephrase it. Hopefully this makes it easier to understand for following makers. Thank you!

Closed 2019-07-04.

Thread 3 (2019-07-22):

Add WiFi configuration menu

janzev, 2019-07-22:
I didn't build this now but I will do it as soosn as possible.

I have an idea which could improve your handheld:
Make wifi configurable through the gui, maybe a settings menu.
If this is not possible it would be very nice if the sd slot could be reachable from the outside (maybe a sd extension cable and a hole in the outer shell.

geaz, 2019-07-25:
Hi!

A external accessible sd slot is planed for my next iteration of this handheld. But I don't know when I will have the time to work on it, because at the moment I am in the process of designing a "little brother" (3 inch display).

But I will check, if I can make the wifi configurable.

janzev, 2019-07-25:
After posting the issue I thought about possibilites making wifi configurable.

You can start other applications through emulationstation if you add another tab. I thought about a little python (or similar) script with a qtGui (qtGui has a virtual keyboard element which could maybe be useable with the console buttons) that lists all available wifi SSIDs and has a textbox for entering the wifi key. If the touchscreen is connected to the pi it could also maybe be used with touch input. Unfortunately a touchscreen doesn't support the retro feeling that this console should have.

If wifi configurable I wouldn't need a SD slot. But a SD slot which is independent from the boot sd card could be the best solution.

batorni, 2019-09-06:
I think I'll work on adding this feature tonight or this weekend. I've noticed some performance issues, and I'm almost sure its due to wifi being enabled 24/7

geaz, 2019-09-07:
Why should we create a "custom" application for it and include it into the system list?

Wouldn't it be really great to add it to the emulation menu itself? The one which comes up, if you press 'start'.
THis shouldn't be to hard. The 'GuiMenu.cpp' in emulation station contains the whole menu and it would be easy to add a custom entry for simplyRetro. Would be really cool I think.

At the moment I am thinking about two menu entries for the custom menu:
- WiFi Enabled (yes, no)
- FTP enabled (yes, no)

Anything else?

janzev, 2019-09-07:
Like mentioned above I think it would be great to configure the WiFi completely through the menu (searching for WiFi networks and entering the password).

geaz, 2019-09-07:
What do you think?

https://streamable.com/1jgjp

Have to do a bit more things, but it looks promising.
I took the onscreen keyboard from Recalbox and modified it a bit to work with the retropie emulation station version, which simplyRetro is using.

batorni, 2019-09-07:
That's lookin' real good! better than my quick idea :)

janzev, 2019-09-07:
Looks great!

geaz, 2019-09-09:
Feature complete now. I will create a new release soon :)

Closed 2019-09-09.

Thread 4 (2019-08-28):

Z5 custom distribution failed

GarGamel55, 2019-08-28:
Hello,
I am very interested in this project !

I printed the pieces and started the electronics. The powering circuit is working ([like here](https://i.imgur.com/bwuunFP.jpg)), but when loading the distribution, it crashes and the Z5 stops (because GPIO19 ?). If I stay press the start button, I can read the error messages ([see photo](https://framapic.org/v2I3r6XNd5pk/qZ1MtVyPF16N.jpg))

I tried with several SD card and 2 different software (Etcher and a linux utilty) and also V1 and V1.1, same results.

You have an idea?

geaz, 2019-08-28:
Hi!

Could you please delete the file "retropower.cfg" from the boot partition and then start it again? This is necessary to test, if the "power script" is the source of failure?

GarGamel55, 2019-08-28:
Thank you Geaz for the quick return :)

It seems that this file is the problem. Now I go to the welcome screen to configure the gamepad.

The retropower.cfg file indicates the Wiring Pi pin "24" of the GPIO 19, which is normal.

geaz, 2019-08-29:
Ok, that confirms my assumption, i guess. It seems, that the "problem" here is, that you don't have the second circuit ready yet. Is this right? As soon as your second circuit (the one with the ADC), is connected the power script should work. Just readd the "retropower.cfg", when you made progress.

I will change the script for the future to be able to switch these functionalities on and off for testing purposes. Thanks!

GarGamel55, 2019-08-30:
Hello,
I mounted all the electronics parts (except the buttons to Pi), but the problem comes back with the file "retropower.cfg".
I checked the diagrams several times, everything seems ok. :(

geaz, 2019-08-30:
Hi,
to bad it does not work, but lets try to fix this together :)
First of all let me recap the current situation (please tell me, if anything in this recap is wrong) and ask a few questions:

In your first post you mentioned that your power button is working - that is, you are able to start the pi by pressing the button, and the pi stays on until the system crashes.

Did you wire both circuits on the exact same GPIOs mentioned in the diagrams?
Are you able to take a picture of you ADC circuit (front and back)?

> I have a doubt, the ground of the "powering circuit" goes to the ground of powerboost 1000 or that of Pi Zero?

Both should work fine.

GarGamel55, 2019-08-30:
> In your first post you mentioned that your power button is working - that is, you are able to start the pi by pressing the button, and the pi stays on until the system crashes.

Yes, that's it and the Pi stops after 10-15 seconds (just after the logo "retrograme" with writing "terminated" at the top left of the screen).
But if I keep pressing the button, the pi don't stops and I can see the error messages as in the picture in my first post. When I release the button the Pi stops.

When i remove the retropower.cfg file, it can see the screen to configure the buttons.

I will recheck all the welds and my circuit and come back to you quickly.

thank you so much

GarGamel55, 2019-08-31:
Here are some pictures of my electronics:

[Overview](https://framapic.org/hzbZn2fxDr7l/2xkCJP4dasvY.jpg)
[PI](https://framapic.org/PFTIJ0a4r163/XcRMH0b8j9j7.jpg)
[Power Circuit (front)](https://framapic.org/UYfxIdOfmI79/TipgXj4LW3WQ.jpg)
[Power Circuit (back)](https://framapic.org/3DWpAMG75geb/bHV2m3KwqWGJ.jpg)

PS : I removed the SD Card to check files, it's normal that the sd slot is empty

geaz, 2019-09-01:
First of all, cool color :)

On a first glance the circuits seem to be ok.
I changed the retroPower tool in such a way now, that the different features can be turned off. Furthermore I added logging to a file. Please use the new release 1.3 to reflash your SD card, if possible.

Look into the boot partition and do a backup of the file retroPower.cfg.
After this please change the configuration like in the following two examples. On each change turn the device on. And rerun the test with the next configuration.
Please tell me with which configuration the device "crashed" and with which configuration it didn't. Furthermore please attach the "retroPower-log.txt" from the boot partition. I hope we can then find the problem :)

Config 1:
```
[features]
shutdown = true
batCheck = false

[pins]
shutdown = 24

[debug]
active = true
writeLog = true
onlyReadAdc = false
```

Config 2
```
[features]
shutdown = false
batCheck = true

[pins]
shutdown = 24

[debug]
active = true
writeLog = true
onlyReadAdc = true
```

GarGamel55, 2019-09-01:
> First of all, cool color :)
It's my children's choice :)

I found the problem (by chance) !!!  When I took the pictures I ripped the powerboost wires (those of the BAT / Lipo pin) and I had to sold them again.

In testing the 3 config above, I had no crash ! So I flashed the previous version to compare and .... no more crashes. The problem was a bad welding on the powerboost (ADC not correctly powered)

 I'm confused for the time lost (but I'm happy to be able to continue the project)

Thanks a lot :)

geaz, 2019-09-01:
Nice! Glad it works now!
Was a nice opportunity to add the additional options to the retropower tool ;)

Will close the issues then.

Closed 2019-09-01.

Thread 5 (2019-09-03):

Audio Circuit Inconsistencies

batorni, 2019-09-03:
In the audio circuit diagram/image, it shows the 5V + on the PAM going to the 5V Pin on the Pi, however, in the image of the completed build, it looks like that line is actually going to pin 1, 3.3V Power.

geaz, 2019-09-03:
You are toally right. Per specification the PAM needs 5V, but it runs fine with 3.3V, too.

batorni, 2019-09-03:
Neat!  I've got mine wired up to a 5V pin, but I'm still trying to get the darn thing to boot, so I was unsure if the audio worked or not

geaz, 2019-09-03:
Are you using the simplyRetro image? If you have any problems with it, feel free to open an issue. Will try my best to help you.

batorni, 2019-09-03:
Yeah, I'm using v1.3 provided here: https://github.com/geaz/simplyRetro-Z5/releases

It doesn't seem to boot via the power button, and I'm not seeing any lights from the powerboost either.
If I plug in power to the pi directly, the powerboost turns on as well as the light on the pi turns on, but the screen isn't turning on either. I think I may have connected the screen power incorrectly. I wired the spliced USB cable to test pads 22 and 23 on the pi, rather than attaching them to test pads 1 and 6 alongside the power from the powerboost.

I need to re-check all my circuits tonight. I went all in and didn't do any intermediate testing so I'm paying for it now :)

I'll open up an issue if I'm still facing issues tonight.

Closed 2019-09-04.

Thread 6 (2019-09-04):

Failing to boot simply retro

batorni, 2019-09-04:
I was able to get my power circuit working successfully to power the pi once the button is pressed, and power is maintained on the Pi and screen.

However, I am unable to get any of the 'retro boy' splash screens or any other signs of a successful boot. I just get a black screen or a 'no signal' on the screen.

I've tried removing the retroPower.cfg as well as modifying the config to enable some debug, but the Pi still refuses to Initialize, and the modifications to retroPower.cfg don't add any debug

I took some pics of my various circuits. (Please excuse my poor soldering skills, this is my first large project!)

Here's the pics: https://imgur.com/a/roYWrGG

geaz, 2019-09-04:
First question, because I can't see it on the pictures: Did you power the screen (micro USB)?

GarGamel55, 2019-09-04:
Hello,

Is there an SD card in the Pi? I do not see it on the pics ....

batorni, 2019-09-04:
Yep, screen is powered, I see it flash and it will go to a blue 'no signal' occasionally.  I've tried flipping the hdmi ribbon cable (because I couldn't figure out the proper orientation) and I get the blue 'no signal' pretty much right away.

geaz, 2019-09-04:
What do you mean with

> because I couldn't figure out the proper orientation

Because the adapters should only fit in one direction.

To further test it:
```
Use another HDMI to Mini HDMI cable and test it
    -> It works: There seems to be something wrong with your "small" hdmi cable.
    -> It doesn't work: Attach the PI to another monitor and test, if you get an output.
```

batorni, 2019-09-04:
The ribbon cable itself when it inserts into the hdmi connectors is the one I struggled with orientation on

geaz, 2019-09-04:
Then please try the steps above to get further results to work with. :)

batorni, 2019-09-04:
I'll pick up an HDMI -> HDMI Mini on my way home from work and give it a shot :)

I've also been thinking, and I do have a 64gb micro SD that I am using and am seeing some issues with the pi zero and trying to boot with a 64gb SD card. I'll hunt down a smaller SD card and try it out tonight as well.

batorni, 2019-09-05:
I was able to get the pi to boot and the power cycle seems to be working properly for both on and off.

I do get an odd emulation station error, as seen here: https://imgur.com/a/2J83vTy

I ended up loading the v1.2 release as the v1.3 release was failing to power off with the button being held. I tried to pull down the repo and rebuild, but it looks like I was missing the wiringPi library and didn't look too much into getting it.

geaz, 2019-09-05:
Glad it works now! May I ask, what fixed your problem?

> I ended up loading the v1.2 release as the v1.3 release was failing to power off with the button being held.

Thank you for the information! Will check, if I added the wrong configuration. The application (retroPower) itself should work as intended. At least on my device :)

> I do get an odd emulation station error, as seen here: https://imgur.com/a/2J83vTy
Yes, EmulationStation will exit, because of this "error". Thats why you are in the prompt after pressing 'start'.

The message indicates, that you don't have any rom on your sd card. Am I right? Just put at least one rom file, a small GB game for example, in the proper folder (/root/roms/). EmulationStation should start correctly after that. After that, please don't forget to [expand the file system](https://github.com/geaz/simplyRetro-Z5#resize-root).

batorni, 2019-09-05:
> May I ask, what fixed your problem?

It actually ended up being a bad HDMI cable from AliExpress. I bought a standard one locally that worked, so I ordered another ribbon cable one from Amazon.

> The message indicates, that you don't have any rom on your sd card. Am I right?

Just tried this before work, and you are right. I had put the .zip in the /root/roms/ folders, not the unzipped file. As soon as I unzipped it, emulation station started correctly and prompted me to configure my controller.

Now I just need to find a keyboard to use with the pi and I can get everything setup and configured :)
I'm almost there!

geaz, 2019-09-05:
Perfect! Will close this issue now.

Closed 2019-09-05.

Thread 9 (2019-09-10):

[Idea] Play a sound at startup

GarGamel55, 2019-09-10:
It might be a good thing to play a sound (like a Gameboy sound) when turning on the Z5 to check that the speakers are working with enable / disable option.

Like that, in case of wrong connection, no need to disassemble (like me right now lol).

That's just a suggestion

GarGamel :)

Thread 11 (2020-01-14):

Cant figure out shutdown using retropie

miitygames, 2020-01-14:
Everything works fine and boots properly.
But when using the button on wont shutdown for some reason.
I've added dtoverlay line in .config and added the retropower.cfg to root
I didn't add the poweridicator pcb can this be the reason?
Hope u can help me figure out how it works

geaz, 2020-01-14:
The power indicator is not necessary for the boot pcb/script. Should be fine on this side.
Are you using the the simplyRetro image?

miitygames, 2020-01-14:
No I'm using the retropie internals are the same and gamecon is installed
for button layout over gpio pins
It seems it does turn on without any problems but it wont turn of

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

miitygames, 2020-01-14:
Sorry not gamecon its retrogame.cfg

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

geaz, 2020-01-14:
Ok, I think this is the "problem".
The power off functionality needs a script running in the background. This script listens for the button press and initiates the shutdown, if the button is held for a few seconds.

I can link the script and a small explanation to this issue by tomorrow.

miitygames, 2020-01-14:
That will be great! Thanks for ure help!

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

miitygames, 2020-01-14:
Just thinking about it, isnt it just the python3 script and then changing
the default to gpio 19 ?
Because I've already was thinking about that last night

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

geaz, 2020-01-15:
This is the "retropower application". The application is resposible for the battery indicator and the shutdown on button hold.

Don't forget to save the retropower config file to your boot partion (same location as your retrogame.cfg). I disabled the battery indicator functionality in the config. Please change the shutdown pin too, if necessary. Hope it helps!

[retropower config.zip](https://github.com/geaz/simplyRetro-Z5/files/4066896/retropower.config.zip)
[retropower.zip](https://github.com/geaz/simplyRetro-Z5/files/4066881/retropower.zip)

geaz, 2020-07-29:
CLosing due to inactivity

Closed 2020-07-29.

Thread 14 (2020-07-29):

Help using Helder's RetroPSU with the shutdown circuit

DoomyDoomer, 2020-07-29:
This isn't really an issue but more of a help request. I'm trying to apply your shutdown circuit to Helder's RetroPSU, which is similar to Adafruits PowerBoost 1000c. It has an EN pin that functions just like the PowerBoost. The problem I'm running into is once the "power" button is pressed, the system halts at "reboot: System halted", meaning it's ready to be rebooted/shutdown but the circuit doesn't seem to send the EN pin to ground to shut down the boost. If I short EN to GND manually, it shuts down. I've triple checked the circuit and I've wired it correctly. The Pi is running on RetroPie with SPI on and your other config.txt values. I manually installed WiringPi as well since it's a dependency on the retropower application. Any help you can offer is appreciated.

geaz, 2020-07-29:
May I ask which distribution you are using? Because it sounds like the GPIO 7 pin is not set to LOW on system shutdown. The powering circuit requires the "dtoverlay" _gpio-poweroff_ which not every distribution has included.

DoomyDoomer, 2020-07-29:
I'm running RetroPie 4.14.98-v7+

geaz, 2020-07-29:
As far as I know it should be included.
Can you check the voltage of GPIO 7 on a running system and a halted one (not powered off)?

DoomyDoomer, 2020-07-29:
3.3v when the system is running and like 6mv when halted, so it appears to be running correctly. I'm stumped.

geaz, 2020-07-29:
Are you sure the ground <-> enable pin connection is correct? Correct resistors, too? If the GPIO 7 is running correctly and your system keeps running on the initial button press, it seems like the ground <-> enable pin is somehow not working as it should.

DoomyDoomer, 2020-07-29:
I think you're right. I'm not sure why I'm having this issue just by looking at the circuit I've built but I'll continue to test. I did bring up the issue to Helder, the maker of the RetroPSU and he put together OSH Park circuit of your Schematic: https://oshpark.com/shared_projects/AFSBND5u This might help people who don't want to mess with stripboard/perfboard :)

geaz, 2020-07-29:
Thats pretty cool, thanks for the link!
I hope you will find the "bug" :)

DoomyDoomer, 2020-07-29:
No problem! Like you, Helder is a huge help with these circuits. I do have one other quick question around the amount of Diodes on your circuit. Usually I see two diodes on circuits such as this. Is the the third diode to reduce the amount of voltage going through to Pin 19?

geaz, 2020-07-30:
Exactly, the third diode drops (resulting in two diodes in series) the voltage to a usable one for pin 19.

DoomyDoomer, 2020-07-30:
After looking over everything several times and making sure all connections are correct to the best of my ability, I'm still not able to power down the boost with the long press of the button. At this point, I wonder if you could take a look at my circuit and let me know if what I've done is correct or not. It's such a simple circuit so I'm struggling to find what is the problem.  I appreciate all of your help so far.

[My Circuit from the front](https://cdn.humblebazooka.com/wp-content/uploads/2020/07/IMG_20200730_103304-scaled.jpg)
_Top Yellow wire is EN, Bottom is CPIO 7, Green is GPIO 19_

[Circuit from the back](https://cdn.humblebazooka.com/wp-content/uploads/2020/07/IMG_20200730_103256-scaled.jpg)

[Circuit back diagram to help explain all the mess](https://cdn.humblebazooka.com/wp-content/uploads/2020/07/simplyRetroZ5_pwr_circ.jpg)

[RetroPSU showing BAT+, EN, 5v PWR, and GND wired to the circuit](https://cdn.humblebazooka.com/wp-content/uploads/2020/07/IMG_20200730_103323-scaled.jpg)

[Pi connections](https://cdn.humblebazooka.com/wp-content/uploads/2020/07/IMG_20200730_103315-scaled.jpg)
_SDA and SDL pins are for a separate battery monitoring script. Pin 7 wire goes to pwr circuit_

My boot config.txt
[config.txt](https://github.com/geaz/simplyRetro-Z5/files/5002371/config.txt)

[My start script for retropower](https://cdn.humblebazooka.com/wp-content/uploads/2020/07/Screenshot-2020-07-30-11.30.45.png)

The "retropower" app is in /usr/bin/ with the proper permissions and does start at boot. It is started at boot by an init.d script called "startRetropower" shown above.

Please let me know if you need anymore information and I appreciate all your help.

geaz, 2020-07-30:
As far as I can see it looks fine. Two questions:
1. By "not able to power down the boost with the long press" you mean, the system gets halted (shutdown is initiated by the retroPower tool), but the power does not get disabled, right?
2. Did you measure with a multimeter, if your enable pin and the GPIO 7 has a working connection? (Just in case: measure the resistance - it should be ~0 Ohm - otherwise the connection is not working).

DoomyDoomer, 2020-07-30:
1. Exactly. It shutsdown the pi but halts at the terminal waiting to be physically turned off.
2. Do you mean I should measure by taking one lead and putting it on my EN and the other on Pin 7 when the system is in "halt" state? If so, when I do this I don't see any reading on my multimeter.

geaz, 2020-07-30:
1. Perfect, the retroPower application is doing it's work correctly. At least something :)
2. You are able to measure it in a powered off state, too. And yes, one lead at the enable pin and the other one on GPIO 7. If you don't get any measures, it means, that the connection between these two points is not working.

You now could use the same method to measure each point in between to get the points where the connection is "lost" (maybe a not working soldering point?).

geaz, 2020-07-30:
One more thing: make sure to use the leads in the correct direction because of the diodes....

DoomyDoomer, 2020-07-30:
Ok this is weird. I used a different multimeter for sanity check. When I have my PSU plugged in (load share) I get 10k ohm between EN and pin 7. If the USB power is removed from the PSU, it's reading as 8.89 and steadily dropping. This is during the halt state. It seems like it's holding a resistance but I could be saying that wrong.

geaz, 2020-07-30:
Could you please also measure the ground <-> enable pin connection, too?

DoomyDoomer, 2020-07-30:
When I test continuity the system reboots unless I hold the leads to the pins, so connection is there ha! 0 ohm when testing resistances.

geaz, 2020-07-30:
So it is "working", if you test with the leads? Did you measure it also in a powered off state?

DoomyDoomer, 2020-07-30:
Right, because touching one lead to EN and another to GND disables the PSU (just like the powerboost). I don't know how I can test resistance without causing it to power off completely, or is that what you're looking for me to try? Again, thanks for continuing to try to help me.

geaz, 2020-07-30:
And one more (sorry): also check GPIO 7 <-> ground

geaz, 2020-07-30:
To summarize what we tested and worked until now:
1. Connections between the following pins is working:
GND <-> EN
GND <-> GPIO 7
GPIO 7 <-> EN (otherwise powering on wouldn't work, if I think about it)
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
DoomyDoomer, 2020-07-30:
That makes sense. 100k isn’t doing the trick but I’ll keep testing >. I almost thought it worked but it turned out I touched both ends of the resistor which powered down the Pi. Getting closer though.

geaz, 2020-07-30:
Maybe you could also try to get smaller than 2k on the EN pin <-> gnd resistor. To do a "harder" pull to ground.

DoomyDoomer, 2020-07-30:
Seems like nothing lower than 2k wants work and anything higher powers the Pi right on.

geaz, 2020-07-31:
With "Seems like nothing lower than 2k wants work" you mean the powering on works as intended, but the powering off not?

DoomyDoomer, 2020-07-31:
What I meant was, when I use a smaller than 2k resistor between EN and GND, the pi won't power on with a button press. 2k seemed to be the sweet spot.

geaz, 2020-07-31:
Ok, did you try anything >100k on the GPIO 7 together with the 2k?

DoomyDoomer, 2020-07-31:
Not yet but I plan to tomorrow. I feel like it's very close if I can just figure out the shutdown.

geaz, 2020-07-31:
Yeah, a working power on was a good step :)
Hoping that >100k is doing the trick for the power off now.

DoomyDoomer, 2020-07-31:
I've hit another issue it seems. I decided to charge the battery while trying out different resistors and realized that now as soon as the USB charger is attached, the Pi comes right on with the 2k resistor in place. It really seems like this circuit just isn't going to work for my PSU :( Too many variables.

geaz, 2020-07-31:
That's all really strange to be honest....and I am very sorry, that it does not work for you. But did you look into https://github.com/Helder1981/OneForAll it seems to be something like retroPower, but for the RetroPSU.

DoomyDoomer, 2020-07-31:
Very strange indeed but it's ok and you have nothing to be sorry about. I really appreciate you spending so much time with me trying to troubleshoot this. I actually have Helder's OneForAll installed and running. Funny enough, the gpio-shutdown pin 7 line in the boot config breaks support for the battery monitoring even though nothing is interfering with SDA and SDL, which it uses. Just another headache I can't solve at the moment.

geaz, 2020-07-31:
As far as I know SPI and I2C are disabled per default on raspian (Retropie is based on it don't know, if they are activating it). You have to activate it in the raspi-config in the "Interfacing" menu.

DoomyDoomer, 2020-07-31:
You are correct but I have activated those in the config.txt but his AllForOne installer does this automatically just in case. If I remove the gpio-shutdown overlay, the monitoring comes back to life. Just another wrinkle :)

geaz, 2020-07-31:
And you should delete retroPower, if you are using OneForAll. It interferes with SPI and I don't know, if this can be a problem for OneForAll.

DoomyDoomer, 2020-07-31:
Good call, I plan to remove it. OneForAll does not have safe shut down for a switch by default. It does however have a monitor that shuts down if the battery hits a certain voltage.

geaz, 2020-07-31:
I just saw in the readme the config option "SHUTDOWN_DETECT". Sounds like this is a safe shutdown by driving a GPIO low. Connect the switch between a GPIO which is pulled high per default (GPIO 7 for example :D) and ground. Insert the GPIO 7 into the config option and now, pressing the switch should shutdown the system. If I understand the readme correctly. But I think it won't disable the PSU?

DoomyDoomer, 2020-07-31:
Right, exactly. You still need a circuit to pull EN to GND to shutdown the PSU. I actually have another circuit I built before trying out yours which used a dual diode and duel mosfet, which triggers the shutdown but does not disable the PSU. I've been chasing the dream of a safe shut down for a long time but I just can't grasp it!

geaz, 2020-07-31:
One last question, did you test to completely disconnect the custom circuit, to test, if the PSU still does only stay powered off with a 2k resistor (want to make sure, that the circuit itself is interfering with this functionality)?

Because you told me, that anything higher would power it on directly, I think, that connecting the USB is pushing the voltage just enough to switch EN to HIGH. This indicates that we have to use a lower resistor.

geaz, 2020-07-31:
I am just refusing to give up now :D

geaz, 2020-07-31:
One more thing: I just created a Discord server (do you have a Discord account?). This is getting very chatty and it would be better to talk there.

https://discord.gg/VFq68m

DoomyDoomer, 2020-07-31:
I was going to suggest the same thing. It looks like that invite is invalid.

geaz, 2020-07-31:
https://discord.gg/92Xk4aS

Hope this one works :)

geaz, 2020-07-31:
Closing this. Further discussion on Discord.

Closed 2020-07-31.

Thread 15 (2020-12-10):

Amazon link to battery is wrong size

itsumimario, 2020-12-10:
The link to the lipo battery is too big for the bracket. It’s also different in size from the one linked to Adafruit, which I assume must be the correct size.

itsumimario, 2020-12-13:
To follow up, as of today I’m not seeing any current listings on Amazon for a 2500mah lipo battery at the 785060 size. Adafruit still has them in stock, so probably best to just delete the Amazon link, which is a 366890 size battery that won’t fit in the bracket.

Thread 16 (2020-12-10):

Amazon link to HDMI+HDMI mini+fpc cable wrong type

itsumimario, 2020-12-10:
The Amazon link goes to a kit that has an HDMI A1 connector (correct), HDMI C2 connector (incorrect—should be C1), and a 20cm FPC cable (incorrect—should be 5cm).

geaz, 2020-12-10:
Thank you for the info! Are you abel to provide the correct links? Otherwise I will just remove them.

itsumimario, 2020-12-13:
I think this one should do the trick: https://www.amazon.com/dp/B07DBVDS6Q/ref=cm_sw_r_cp_awdb_imm_t1_BUy1Fb1F53F48

I happened to already have the correct connector (from a previous project) so I can’t vouch for this particular item listing, but it looks like it fits the bill.

Also, one thing I’ve noticed as a word of warning to anyone reading this, it appears some manufacturers have swapped how they define C1 and C3 HDMI mini connectors. So for example, in the Amazon link above, that’s a C3 connector and that’s the one that’s needed, even though other sellers will sometimes call it C1.

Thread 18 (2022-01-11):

First Test Boot

ccraig1984, 2022-01-11:
Trying to make sure everything will boot and nothing. I have it setup with the AC power, OTG cable to the screen and the supplied hdmi cable with a brand new PNY 32gb sd card. I have used Etcher portable and Etcher installed. I have used win32diskimager and still to no avail. Am I doing something wrong? I can get noobs to work on the preloaded sd card and on a new 32gb sd card. I am using sdcard.img version 1.4.
Edit: I can get the splash screen if I turn it on in the config but otherwise I just get a black screen. It doesn't say no input but a black screen as in that is all that it is receiving.

geaz, 2022-01-12:
As far as I remember it should be ok to flash with Etcher and use the Image on a Raspberry Pi Zero. Please be aware that it is not working with any other Pi (will also not work on a Pi Zero 2).

ccraig1984, 2022-01-12:
Well then that is my problem, I am using a pi zero 2. Oh well, I can still configure it to use the battery monitor as well as the power on and off button. Thank you and problem resolved.

Closed 2022-01-12.

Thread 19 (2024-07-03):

Modify build for Pi Zero 2

elevins, 2024-07-03:
Any tips on how to approach this?

geaz, 2024-07-11:
As far as I know, the Pi Zero 2 is same size as the Pi Zero. Should be a drop in replacement.
But the provided os image will probably not work with the Pi Zero 2.

elevins, 2024-07-12:
Yeah, I used it as a drop-in replacement and the image would not boot. Saw this issue https://github.com/geaz/simplyRetro-Z5/issues/18 and it seems to be the culprit.

Since I've already wired everything up and the gpio used are not compatible with retropie or recalbox it looks like i have two choices.

1) rewire the gpio and use one of the other os designed for running retro games
2) recompile the os for use with the rpi2 zero

Wondering if you had any docs or a tutorial you used to setup the embedded linux os. so i could try number 2 before i resort to path 1.

geaz, 2024-07-20:
Your best bet is the official buildroot documentation: https://buildroot.org/
Its quit great and was a huge help the time I created the image.

As a third option you could also take retropie, for example, and just compile the "retroPower" application and use it within retropie for the battery indicator/power circuit.

elevins, 2024-07-28:
Thanks will attempt to use buildroot and recompile the provided source files for the zero 2. Think the issue may be the upgrade to the new cpu for the rpi zero 2. Will update/close the issue with my findings.

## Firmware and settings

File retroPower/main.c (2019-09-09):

#include <stdlib.h>
#include <stdio.h>
#include <unistd.h>

#include <wiringPi.h>
#include <wiringPiSPI.h>

#include "debugLogger.h"
#include "powerConfig.h"
#include "checkBat.h"
#include "powerOff.h"

powerConfig config;
char configFile[] = "/boot/retropower.cfg";
int checkIntervalInSec = 2;

int main(int argc, char *argv[]) 
{    
    if(access(configFile, F_OK) != -1)
    {
        config = readPowerConfig(configFile);
        writeDebug(config, "Shutdown Pin: %d", config.shutdownPin);
        writeDebug(config, "Shutdown Active: %s", config.shutdownActive ? "true" : "false");
        writeDebug(config, "Check Bat Active: %s", config.checkActive ? "true" : "false");
        writeDebug(config, "Only Read ADC: %s", config.onlyReadAdc ? "true" : "false");

        wiringPiSetup();
        wiringPiSPISetup(0, 4*1000*1000);
        if(config.shutdownPin != -1 && config.shutdownActive) 
        {           
            pinMode(config.shutdownPin, INPUT);
        }          

        if(config.shutdownActive || config.checkActive)
        {
            while(1) 
            {
                if(config.shutdownActive) checkPowerOff(config);
                if(config.checkActive) checkBat(config);
                sleep(checkIntervalInSec);
            }
        }
    } 
}

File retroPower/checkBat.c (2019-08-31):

#include <time.h>
#include <stdint.h>
#include <stdio.h>
#include <stdlib.h>
#include <math.h>
#include <string.h>

#include <wiringPi.h>
#include <wiringPiSPI.h>

#include "checkBat.h"
#include "debugLogger.h"
#include "powerConfig.h"

char iconName[] = "battery";
char filePath[] = "/root/.retropower/";
char extension[] = ".png";
char iconFilePath[50];
char lastShownImage[50];

int checkBatIntervalInSec = 10;
time_t lastBatCheck = 0;

float voltageDivider(float r1, float r2, float vin) 
{
    return vin * (r2 / (r1 + r2));
}

int analogPowerRead(int adcnum)
{ 
    unsigned int commandout = 0;
    unsigned int adcout = 0;

    commandout = adcnum & 0x3;  // only 0-7
    commandout |= 0x18;     // start bit + single-ended bit

    uint8_t spibuf[3];

    spibuf[0] = commandout;
    spibuf[1] = 0;
    spibuf[2] = 0;

    wiringPiSPIDataRW(0, spibuf, 3);    

    adcout = ((spibuf[1] << 8) | (spibuf[2])) >> 4;

    return adcout;
} 

void checkBat(const powerConfig config)
{
    if(analogPowerRead(1) > 0)
    {
        sprintf(iconFilePath, "%s%s-%s%s", filePath, iconName, "charging", extension);
    }
    else if(lastBatCheck == 0 || time(0) >= lastBatCheck + checkBatIntervalInSec)
    {
        lastBatCheck = time(0);

        // The Max Voltage we get from the BAT Pin
        float maxVoltageBat = voltageDivider(DIVIDER_R1, DIVIDER_R2, BAT_MAX);
        // The Min Voltage we get from the BAT Pin
        float minVoltageBat = voltageDivider(DIVIDER_R1, DIVIDER_R2, BAT_MIN);
        // Because our VREF is 3.3v coming from PI and this will be not equal to 
        // our max voltage coming from the BAT Pin
        // we have to calculate a conversion factor
        float correctionFactor = 1 / (maxVoltageBat / GPIO_MAX);

        float batRelativeRead = analogPowerRead(0);
        float batCorrectedRead = batRelativeRead * correctionFactor; 
        
        float effectiveRangeStart = (1024 / maxVoltageBat) * minVoltageBat;
        float effectiveRange = 1024 - effectiveRangeStart;

        float batLevelEffective = batCorrectedRead - effectiveRangeStart;
        float batPercentage = batLevelEffective / effectiveRange;
         
        int roundedBatPercentage = round(batPercentage*100);

        if(batPercentage < 0.03 && !config.onlyReadAdc)
        {
            writeDebug(config, "Power Off initiated (Bat Low)");
            system("halt");
        }
        if(batPercentage < 0.03)
        {
            writeDebug(config, "Only Read ADC Mode! Battery Low!");
        }
        else if(batPercentage < 0.1)
        {
            sprintf(iconFilePath, "%s%s-%s%s", filePath, iconName, "alert", extension);
        }
        else if(roundedBatPercentage < 95) 
        {
            int tenthRoundedBatPercentage = roundedBatPercentage - (roundedBatPercentage%10);
            sprintf(iconFilePath, "%s%s-%d%s", filePath, iconName, tenthRoundedBatPercentage, extension);
        }
        else 
        {
            sprintf(iconFilePath, "%s%s%s", filePath, iconName, extension);
        }

        writeDebug(config, "Max Voltage Bat (After Divider): %.6f", maxVoltageBat);
        writeDebug(config, "Min Voltage Bat (After Divider): %.6f", minVoltageBat);
        writeDebug(config, "Correction Factor (Caused By Divider): %.6f", correctionFactor);
        writeDebug(config, "Bat Relative Read: %.6f", batRelativeRead);
        writeDebug(config, "Bat Corrected Read: %.6f", batCorrectedRead);
        writeDebug(config, "Effective Range Start: %.6f", effectiveRangeStart);
        writeDebug(config, "Effective Range: %.6f", effectiveRange);
        writeDebug(config, "Bat Level Effective: %.6f", batLevelEffective);
        writeDebug(config, "Bat Percentage: %.6f", batPercentage);
    }
        
    if(strcmp(lastShownImage, iconFilePath) != 0)
    {
        if(config.debugActive)
        {            
            writeDebug(config, "%s\n", iconFilePath);
        }
        
        strcpy(lastShownImage, iconFilePath);
        system("killall -9 pngview");

        char buf[100];
        sprintf(buf, "%s %s &", "pngview -b 0x0000 -d 0 -l 15000 -y 5 -x 775", iconFilePath);
        system(buf);     
    }   
}

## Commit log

2019-05-29 First checkin
    [retrogame.cfg]
2019-05-29 Added STLs
    [2x Button.stl, 2x Shoulder Button Mount.stl, 2x Shoulder Button.stl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]
2019-05-29 Changed PowerOff Script
2019-05-30 PowerOff Script changes
2019-06-02 Some image fixes and Power Script changes
    [main.c]
2019-06-06 Added retropower.cfg to fix #1 and Build chapter progress
    [main.c]
2019-06-08 Power circuit explanation
2019-06-09 Build chapter progress
    [retrogame.cfg]
2019-06-13 Changed Hotkey to fix issue with Arcade Coin Insert
2019-07-18 Changed battery icons and added GBA emulator
2019-08-31 Added US BOM
2019-08-31 Added alternative BOM to Readme
2019-08-31 Added more options to the power tool
2020-04-15 Update BOM - US.md
2020-05-09 Add 3MF (3D2P)
    [simplyRetro z5.3mf]
2020-07-09 BOM - DE_2020
2020-07-09 Rename BOM - DE_2020.md to BOM - DE.md
2022-04-20 Update US BOM #15 #16
